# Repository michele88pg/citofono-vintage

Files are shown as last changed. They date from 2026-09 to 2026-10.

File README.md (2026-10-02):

# Pronto — a smart door intercom inside a vintage rotary phone

🇬🇧 English · [🇮🇹 Italiano](#-versione-italiana)

**Pronto** is an open-hardware circuit board that turns a vintage rotary phone into a **smart door intercom**. The phone looks and works exactly as before:

- lift the handset to talk to whoever rang;
- dial a number and the street door opens.

On top of that you get:

- a notification on your phone when someone rings;
- remote door opening;
- Home Assistant integration and, through Home Assistant, Google Home, Apple Home and Alexa.

The board has **exactly the shape of the original one** and screws into its place, with no drilling or changes to the shell.

> **Compatibility:** **Siemens / Italtel S62** phones (wall-mounted version) and **URMET 4+N** analog intercom systems, very common in Italian apartment buildings.
> Other phones and systems: see [Compatibility](docs/compatibilita.md) (in Italian).

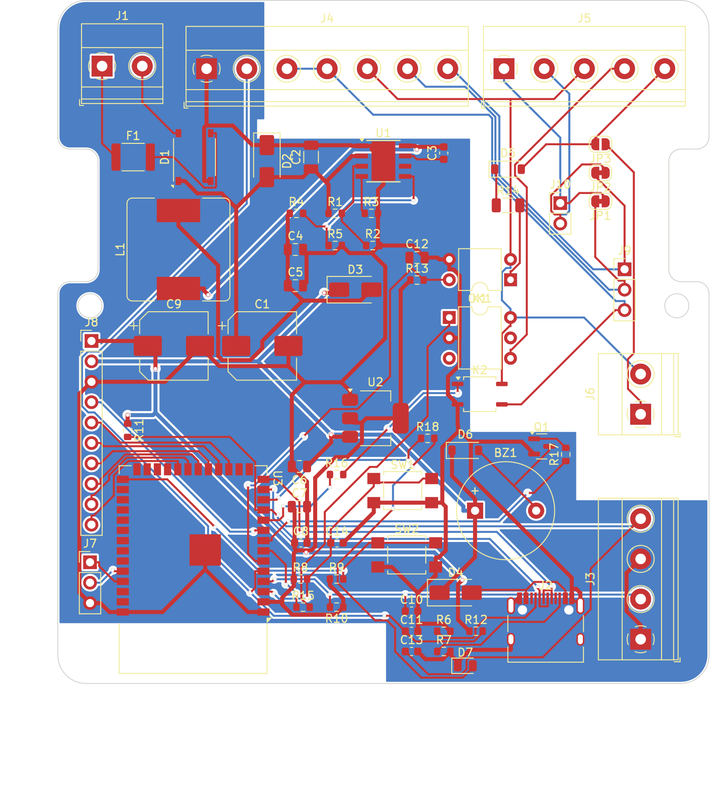
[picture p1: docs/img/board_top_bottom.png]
Pronto board rev 0.5: component side and solder side


---

> [!WARNING]
> **Prototype stage.** Board rev 0.5 has been ordered (5 assembled boards) but **has not been tested yet**.
> The firmware is validated, but not yet tried on real hardware.
> You are welcome to build one now, but expect to fix something along the way. Current status is in the [CHANGELOG](CHANGELOG.md).

## Contents

- [What it does](#what-it-does)
- [How it works, in short](#how-it-works-in-short)
- [Board pinout](#board-pinout)
- [What you need](#what-you-need)
- [Getting started](#getting-started)
- [Repository layout](#repository-layout)
- [Roadmap](#roadmap)
- [Safety](#safety)
- [Contributing](#contributing)
- [Licenses](#licenses)
- [🇮🇹 Versione italiana](#-versione-italiana)

## What it does

| Feature | How it works |
|---|---|
| **Answering** | As always: lift the handset and talk. Audio passes through in analog form; the board does not touch it |
| **Open with the dial** | Dial any number and the door opens, as many vintage intercom phones did. Optional: a **secret code** to dial |
| **Ringing** | When someone rings at the street door, the board's buzzer plays a classic double ring. The phone's original bells can be connected experimentally |
| **Phone notification** | A notification arrives with an **"Open the door"** button in it |
| **Remote opening** | From Home Assistant, the notification, a voice assistant or the board's own web page |
| **Do not disturb** | Silences the ring; the notification still arrives |
| **Auto-open** | Opens by itself when someone rings, handy for parties or expected deliveries. Turns itself off on reboot |
| **History** | Last call, last opening, call counter |
| **Local web page** | `http://citofono-vintage.local` works even without Home Assistant |
| **Remote listening and talking** | *In development:* an add-on audio board with an ES8311 codec. See [hardware/audio-board](hardware/audio-board/README.md) |

## How it works, in short

```mermaid
flowchart LR
    subgraph IMP["URMET 4+N intercom system"]
        CA["CA: call"]
        APR["9 and 6: door release"]
        FON["1 and 2: audio"]
    end
    subgraph SCH["Pronto board, inside the phone"]
        OK1["OK1 optocoupler<br/>detects the call"]
        K1["K1 PhotoMOS<br/>opens the door"]
        K2["K2 PhotoMOS<br/>simulates handset lifted"]
        ESP["ESP32-S3<br/>ESPHome firmware"]
        BZ["Buzzer"]
    end
    subgraph TEL["Rotary phone"]
        DISCO["Rotary dial"]
        CORN["Handset and hook switch"]
    end
    HA["Home Assistant<br/>notifications, Google, Apple, Alexa"]
    CA --> OK1 --> ESP
    ESP --> K1 --> APR
    ESP --> K2 -->|enables| FON
    DISCO --> ESP
    CORN --> ESP
    FON <-->|analog audio| CORN
    ESP --> BZ
    ESP <-->|WiFi| HA
```

**Isolation from the building system.** The board has no direct electrical connection to the shared intercom line. It detects the call with an optocoupler and opens the door with PhotoMOS solid-state relays, which are optically isolated. The electronics' ground stays separate from the intercom line.

The full description is in **[docs/come-funziona.md](docs/come-funziona.md)** (in Italian): every circuit block, the opening sequences, dial timing and firmware safety features.

## Board pinout

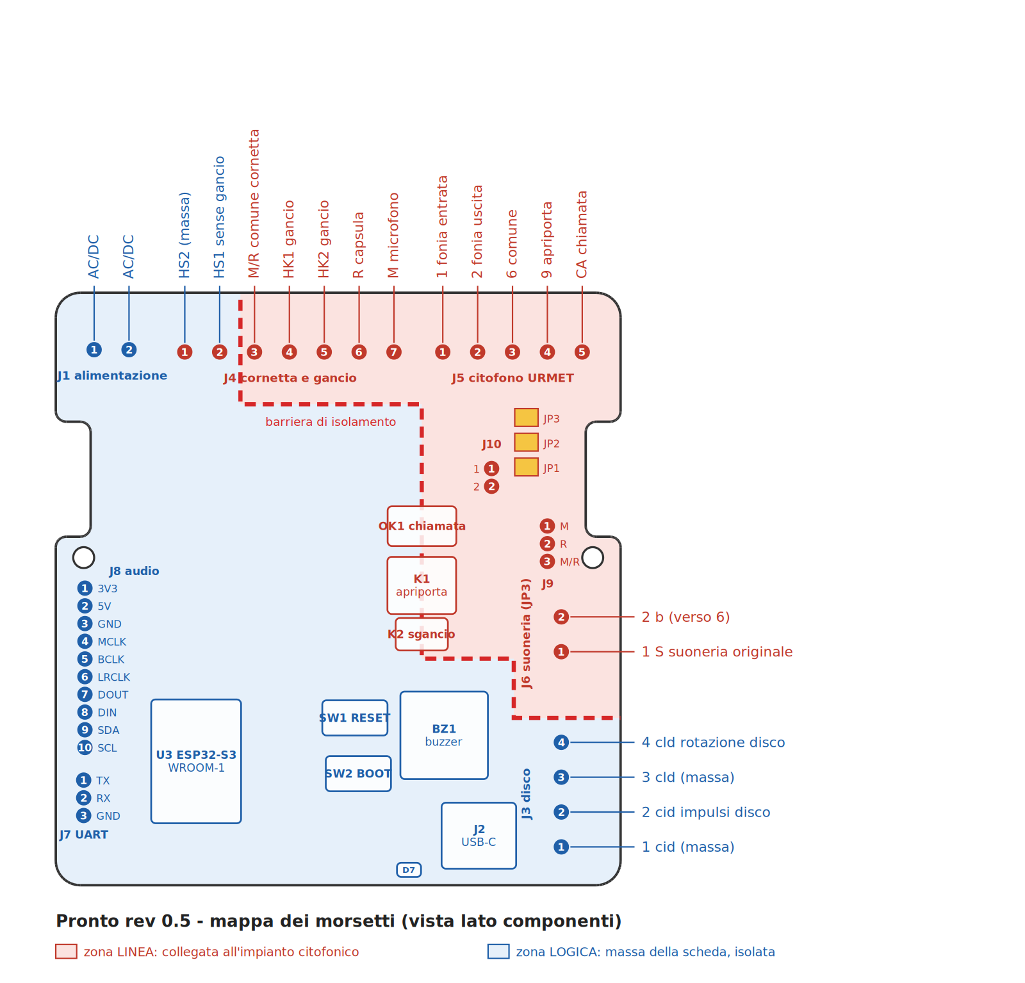
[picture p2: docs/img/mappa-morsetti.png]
Pronto rev 0.5 terminal map


The labels are in Italian. Key terms:

| Label | Meaning |
|---|---|
| alimentazione | power input |
| cornetta, capsula, microfono | handset, earpiece, microphone |
| gancio | hook switch |
| fonia entrata / uscita | audio in (from street) / audio out (to street) |
| comune | common |
| apriporta | door release |
| chiamata | call |
| suoneria | ringer bells |
| disco, impulsi, rotazione | dial, pulses, dial-in-motion contact |
| massa | ground |
| zona linea / zona logica | intercom-line side / isolated logic side |
| barriera di isolamento | isolation barrier |

Step-by-step wiring of dial, hook, handset and intercom is in [docs/installazione.md](docs/installazione.md).

## What you need

| Item | Notes |
|---|---|
| An **S62 wall phone** | Found at flea markets and online. Dial, handset and hook switch must work |
| The **Pronto** board | Order it pre-assembled from JLCPCB with the ready-made files in [`hardware/mainboard/production`](hardware/mainboard/production): see [Ordering the board](docs/ordinare-la-scheda.md) |
| Hand-soldered parts | The K1 relay (through-hole, from DigiKey/Mouser) and the screw terminals. Easy soldering |
| **Power** | URMET 4+N systems do not power the indoor unit. You need a supply on J1, **9–36 V DC or 9–24 V AC** (for example 12 V DC, 1 A), or **5 V from USB-C** |
| Home WiFi | Home Assistant is recommended but not required |
| Tools | Soldering iron, multimeter, screwdriver. A computer with [ESPHome](https://esphome.io) for the first firmware upload over USB-C |

Indicative parts cost is about €40 per board for 5 assembled prototypes. It drops a lot with larger quantities.

## Getting started

The detailed guides are currently in Italian; translations are welcome.

1. **Check compatibility** of your intercom and phone: [docs/compatibilita.md](docs/compatibilita.md)
2. **Order and assemble the board:** [docs/ordinare-la-scheda.md](docs/ordinare-la-scheda.md)
3. **Upload the firmware:** [firmware/README.md](firmware/README.md)
4. **Install the board in the phone and wire it to the intercom:** [docs/installazione.md](docs/installazione.md)
5. **Test it, one step at a time:** [docs/collaudo.md](docs/collaudo.md)
6. **Connect Home Assistant and notifications:** [docs/home-assistant.md](docs/home-assistant.md)

FAQ: [docs/faq.md](docs/faq.md)

## Repository layout

```
citofono-vintage/
├── hardware/
│   ├── mainboard/          Main board (KiCad): schematic, PCB, PDF
│   │   └── production/     Gerber, BOM and placement files ready for JLCPCB
│   ├── audio-board/        ES8311 audio board (remote listen/talk), schematic only
│   └── mechanical/         S62 board outline as DXF
├── firmware/               ESPHome firmware (+ package for the audio board)
├── home-assistant/         Example automations (notification with "Open" button)
├── docs/                   Documentation: how it works, installation, testing...
├── LICENSES/               License texts
└── CHANGELOG.md            Revision history
```

## Roadmap

- [x] Mechanical survey of the original S62 board and DXF outline
- [x] Schematic and PCB rev 0.5 in the original board's shape
- [x] ESPHome firmware with dial opening, notifications and remote opening
- [x] Audio board schematic (ES8311) for remote listening and talking
- [ ] Testing the rev 0.5 prototypes on a real URMET system
- [ ] Audio board PCB and voice calls on the phone
- [ ] Photo assembly guide and project website
- [ ] Cheaper, simplified board (ESP32 chip directly on the board, fewer parts)
- [ ] Support for other 4+N systems and other rotary phones
- [ ] English translation of the documentation

## Safety

- The board works only with **extra-low voltages**: 12 V AC call signal, at most about 30 V DC on the intercom line, 9–36 V supply. **Never connect it to 230 V mains.**
- The intercom system is often **shared by the whole building**. Make sure you are allowed to work on your indoor unit. Disconnect the old intercom only after identifying the terminals with a multimeter.
- Remote opening really opens your front door. Protect Home Assistant and the board's web page with strong passwords, and never expose the board directly to the Internet.
- The project is provided **as is**, without warranty (see [Licenses](#licenses)). Whoever builds and installs it is responsible for it.

## Contributing

The most valuable contribution right now is knowing **which intercom systems and phones it works with**.
If you try it, open a [compatibility report](../../issues/new?template=compatibilita.md), even if it does not work. Include make and model of the intercom and phone, and your measurements.

Fixes, assembly photos and translations are welcome: see [CONTRIBUTING.md](CONTRIBUTING.md).

## Licenses

| Part | License |
|---|---|
| Hardware (`hardware/`) | [CERN-OHL-S v2](LICENSES/CERN-OHL-S-2.0.txt) |
| Firmware and configuration (`firmware/`, `home-assistant/`) | [MIT](LICENSES/MIT.txt) |
| Documentation and images (`docs/`, `.md` files) | [CC BY-SA 4.0](LICENSES/CC-BY-SA-4.0.txt) |

Details are in [LICENSE.md](LICENSE.md).

**Trademarks.** Siemens, Italtel and URMET are trademarks of their respective owners. They are mentioned only to indicate compatibility. This is an independent project, not affiliated with or endorsed by them.
The S62 phone is a classic of Italian industrial design, designed by Lino Saltini in the 1960s. This project does not reproduce its shell: it only replaces the electronics inside.

---

## 🇮🇹 Versione italiana

[🇬🇧 English](#contents) · 🇮🇹 Italiano

**Pronto — il citofono smart dentro un telefono a disco**

**Pronto** è una scheda elettronica open hardware che trasforma un telefono a disco d'epoca in un **citofono smart**. Il telefono resta com'è, fuori e nell'uso:

- alzi la cornetta per parlare con chi ha suonato;
- componi un numero con il disco e il portone si apre.

In più arrivano:

- la notifica sul cellulare quando qualcuno suona;
- l'apertura del portone da remoto;
- l'integrazione con Home Assistant e, tramite Home Assistant, con Google Home, Apple Home e Alexa.

La scheda ha **esattamente la forma della scheda originale** e si avvita al suo posto, senza forare né modificare il guscio.

> **Compatibilità:** telefoni **Siemens / Italtel S62** (versione da parete) e impianti citofonici **URMET 4+N** analogici.
> Altri telefoni e impianti: vedi [Compatibilità](docs/compatibilita.md).

Scheda Pronto rev 0.5: lato componenti e lato saldature

> [!WARNING]
> **Progetto in fase di prototipo.** La scheda rev 0.5 è stata ordinata (5 esemplari assemblati) ma **non è ancora stata collaudata**.
> Il firmware è validato, ma non ancora provato sull'hardware vero.
> Se vuoi costruirla adesso sei il benvenuto, ma aspettati di dover correggere qualcosa. Lo stato aggiornato è nel [CHANGELOG](CHANGELOG.md).

### Indice

- [Cosa fa](#cosa-fa)
- [Come funziona in breve](#come-funziona-in-breve)
- [Mappa dei morsetti](#mappa-dei-morsetti)
- [Cosa serve](#cosa-serve)
- [Da dove iniziare](#da-dove-iniziare)
- [Struttura della repository](#struttura-della-repository)
- [Prossimi passi](#prossimi-passi)
- [Sicurezza](#sicurezza)
- [Contribuire](#contribuire)
- [Licenze](#licenze)

### Cosa fa

| Funzione | Come si usa |
|---|---|
| **Rispondere** | Come sempre: alzi la cornetta e parli. L'audio passa in analogico, la scheda non lo tocca |
| **Aprire con il disco** | Componi un numero qualsiasi e il portone si apre, come facevano molti citofoni-telefono d'epoca. Opzionale: un **codice segreto** da comporre |
| **Suoneria** | Quando suonano al portone, il buzzer della scheda squilla con un doppio squillo da telefono. La suoneria originale a campanelli si può collegare in via sperimentale |
| **Notifica sul cellulare** | Arriva una notifica con il pulsante **"Apri il portone"** dentro |
| **Apertura remota** | Da Home Assistant, dalla notifica, dall'assistente vocale o dalla pagina web della scheda |
| **Non disturbare** | Silenzia lo squillo; la notifica arriva comunque |
| **Apertura automatica** | Apre da sola alla chiamata, utile per feste o consegne attese. Si disattiva da sola al riavvio |
| **Storico** | Ultima chiamata, ultima apertura, contatore delle chiamate |
| **Pagina web locale** | `http://citofono-vintage.local` funziona anche senza Home Assistant |
| **Ascolto e risposta da remoto** | *In sviluppo:* scheda audio aggiuntiva con codec ES8311. Vedi [hardware/audio-board](hardware/audio-board/README.md) |

### Come funziona in breve

```mermaid
flowchart LR
    subgraph IMP["Impianto citofonico URMET 4+N"]
        CA["CA: chiamata"]
        APR["9 e 6: apriporta"]
        FON["1 e 2: fonia"]
    end
    subgraph SCH["Scheda Pronto, dentro il telefono"]
        OK1["OK1 optoisolatore<br/>sente la chiamata"]
        K1["K1 PhotoMOS<br/>apre il portone"]
        K2["K2 PhotoMOS<br/>simula la cornetta alzata"]
        ESP["ESP32-S3<br/>firmware ESPHome"]
        BZ["Buzzer"]
    end
    subgraph TEL["Telefono a disco"]
        DISCO["Disco combinatore"]
        CORN["Cornetta e gancio"]
    end
    HA["Home Assistant<br/>notifiche, Google, Apple, Alexa"]
    CA --> OK1 --> ESP
    ESP --> K1 --> APR
    ESP --> K2 -->|abilita| FON
    DISCO --> ESP
    CORN --> ESP
    FON <-->|audio analogico| CORN
    ESP --> BZ
    ESP <-->|WiFi| HA
```

**Isolamento dall'impianto.** La scheda non ha nessun collegamento elettrico diretto con l'impianto condominiale. Sente la chiamata con un optoisolatore e apre il portone con relè allo stato solido PhotoMOS, che isolano otticamente. La massa dell'elettronica resta così separata dalla linea del citofono.

Il funzionamento completo è in **[docs/come-funziona.md](docs/come-funziona.md)**: ogni blocco del circuito, le sequenze di apertura, i tempi del disco e le sicurezze del firmware.

### Mappa dei morsetti

Mappa dei morsetti della scheda Pronto rev 0.5

Il collegamento passo passo di disco, gancio, cornetta e citofono è in [docs/installazione.md](docs/installazione.md).

### Cosa serve

| Cosa | Note |
|---|---|
| Un telefono **S62 da parete** | Si trova nei mercatini e online. Deve avere disco, cornetta e gancio funzionanti |
| La scheda **Pronto** | Si ordina già assemblata da JLCPCB con i file pronti in [`hardware/mainboard/production`](hardware/mainboard/production): vedi [Ordinare la scheda](docs/ordinare-la-scheda.md) |
| Componenti da saldare a mano | Il relè K1 (a foro passante, da DigiKey/Mouser) e le morsettiere a vite. Sono saldature facili |
| **Alimentazione** | L'impianto URMET 4+N non alimenta il posto interno. Serve un alimentatore su J1, **9–36 V DC o 9–24 V AC** (per esempio 12 V DC da 1 A), oppure **5 V da USB-C** |
| WiFi di casa | Home Assistant è consigliato ma non obbligatorio |
| Attrezzatura | Saldatore, tester, cacciavite. Un computer con [ESPHome](https://esphome.io) per il primo caricamento del firmware via USB-C |

Il costo indicativo dei componenti è di circa 40 € a scheda su 5 prototipi assemblati. Scende molto con quantità maggiori.

### Da dove iniziare

1. **Verifica la compatibilità** del tuo impianto e del tuo telefono: [docs/compatibilita.md](docs/compatibilita.md)
2. **Ordina e monta la scheda:** [docs/ordinare-la-scheda.md](docs/ordinare-la-scheda.md)
3. **Carica il firmware:** [firmware/README.md](firmware/README.md)
4. **Installa la scheda nel telefono e collegala al citofono:** [docs/installazione.md](docs/installazione.md)
5. **Collauda, un passo alla volta:** [docs/collaudo.md](docs/collaudo.md)
6. **Collega Home Assistant e le notifiche:** [docs/home-assistant.md](docs/home-assistant.md)

Domande frequenti: [docs/faq.md](docs/faq.md)

### Struttura della repository

```
citofono-vintage/
├── hardware/
│   ├── mainboard/          Scheda principale (KiCad): schema, PCB, PDF
│   │   └── production/     Gerber, BOM e posizionamento pronti per JLCPCB
│   ├── audio-board/        Scheda audio ES8311 (ascolto e risposta da remoto), solo schema
│   └── mechanical/         Contorno della scheda S62 in DXF
├── firmware/               Firmware ESPHome (+ pacchetto per la scheda audio)
├── home-assistant/         Automazioni di esempio (notifica con pulsante "Apri")
├── docs/                   Documentazione: funzionamento, installazione, collaudo...
├── LICENSES/               Testi delle licenze
└── CHANGELOG.md            Storia delle revisioni
```

### Prossimi passi

- [x] Rilievo meccanico della scheda originale S62 e contorno in DXF
- [x] Schema elettrico e PCB rev 0.5 nella forma della scheda originale
- [x] Firmware ESPHome con apertura da disco, notifiche e apertura remota
- [x] Schema della scheda audio (ES8311) per ascolto e risposta da remoto
- [ ] Collaudo dei prototipi rev 0.5 su impianto URMET reale
- [ ] PCB della scheda audio e integrazione della chiamata vocale sul cellulare
- [ ] Guida fotografica al montaggio e sito del progetto
- [ ] Versione più economica e semplificata della scheda (ESP32 direttamente sulla scheda, meno componenti)
- [ ] Compatibilità con altri impianti 4+N e con altri telefoni a disco
- [ ] Traduzione in inglese della documentazione

### Sicurezza

- La scheda lavora solo con **bassissime tensioni**: 12 V AC di chiamata, al massimo circa 30 V DC sulla linea citofonica, 9–36 V di alimentazione. **Non va mai collegata alla rete a 230 V.**
- L'impianto citofonico è spesso **condominiale**. Prima di intervenire sul tuo posto interno, verifica di poterlo fare. Scollega il vecchio citofono solo dopo aver identificato i morsetti con il tester.
- L'apertura remota apre davvero il portone di casa. Proteggi Home Assistant e la pagina web della scheda con password robuste, e non esporre la scheda direttamente su Internet.
- Il progetto è fornito **così com'è**, senza garanzie (vedi [Licenze](#licenze)). Chi lo costruisce e lo installa ne è responsabile.

### Contribuire

Il contributo più prezioso adesso è sapere **su quali impianti e telefoni funziona**.
Se lo provi, apri una [segnalazione di compatibilità](../../issues/new?template=compatibilita.md), anche se non funziona. Servono marca e modello dell'impianto e del telefono, e le misure fatte.

Correzioni, foto del montaggio e traduzioni sono benvenute: vedi [CONTRIBUTING.md](CONTRIBUTING.md).

### Licenze

| Parte | Licenza |
|---|---|
| Hardware (`hardware/`) | [CERN-OHL-S v2](LICENSES/CERN-OHL-S-2.0.txt) |
| Firmware e configurazioni (`firmware/`, `home-assistant/`) | [MIT](LICENSES/MIT.txt) |
| Documentazione e immagini (`docs/`, file `.md`) | [CC BY-SA 4.0](LICENSES/CC-BY-SA-4.0.txt) |

I dettagli sono in [LICENSE.md](LICENSE.md).

**Marchi.** Siemens, Italtel e URMET sono marchi dei rispettivi proprietari. Sono citati solo per indicare la compatibilità. Questo è un progetto indipendente, non affiliato né approvato da loro.
Il telefono S62 è un classico del design industriale italiano, disegnato da Lino Saltini negli anni '60. Questo progetto non ne riproduce il guscio: ne sostituisce solo l'elettronica interna.

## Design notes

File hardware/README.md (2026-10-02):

# Hardware

| Cartella | Contenuto | Stato |
|---|---|---|
| [`mainboard/`](mainboard) | Scheda principale: sorgenti KiCad e file di produzione per JLCPCB | rev 0.5, prototipi ordinati, collaudo in corso |
| [`audio-board/`](audio-board) | Scheda audio ES8311 per ascolto e risposta da remoto | rev 0.1, solo schema |
| [`mechanical/`](mechanical) | Contorno della scheda originale S62 in DXF | rilevato su un esemplare reale |

## Licenza

Tutto il contenuto di questa cartella è rilasciato con la licenza **CERN Open Hardware Licence Version 2 – Strongly Reciprocal** (CERN-OHL-S-2.0). Il testo completo è in [`LICENSES/CERN-OHL-S-2.0.txt`](../LICENSES/CERN-OHL-S-2.0.txt).

Source location: https://github.com/michele88pg/citofono-vintage

Chi produce o distribuisce schede basate su questo progetto, anche modificate, deve:
- rendere disponibili i sorgenti con la stessa licenza;
- mantenere questa indicazione della sorgente.

Copyright © 2026 Michele Matteucci

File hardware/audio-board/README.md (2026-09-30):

# Scheda audio ES8311 (rev 0.1)

> **Stato:** solo schema. Il PCB non è ancora disegnato e la scheda non è ancora stata provata.

La scheda principale rev 0.5 apre il portone e rileva le chiamate, ma l'audio del citofono non passa dall'ESP32. Questa schedina si collega ai connettori già previsti **J8/J9/J10** e aggiunge due funzioni:

- **Ascolto e registrazione.** La voce che arriva dal posto esterno (linea 1) entra nel codec e l'ESP32 la riceve come un microfono.
- **Risposta da remoto.** La voce dal telefono esce dal codec e viene mandata sulla linea 2 al posto esterno. La cornetta resta esclusa.

Lo schema è **completo e verificato rete per rete** (netlist esportata e controllata). Il PCB conviene disegnarlo dopo il collaudo della scheda principale: vedi "Prima di ordinare".

## File

| File | Contenuto |
|---|---|
| `CitofonoAudio.kicad_sch` | Schema (formato KiCad 7, si apre in KiCad 10 che lo aggiorna) |
| `CitofonoAudio.kicad_sym` + `sym-lib-table` | Libreria di progetto: simboli ES8311 e SM-LP-5001 |
| `CitofonoAudio_schematic.pdf` | Schema stampabile |
| `BOM_AudioBoard.csv` | Distinta con i codici LCSC dei componenti principali; i campi vuoti vanno completati prima dell'ordine |

## Come funziona

```
LINEA URMET                          |  LATO LOGICA (GND scheda)
                                     |
linea 1 --C11--R4--[T1 600:600]------|--C12/C13--> MIC1P/N  ES8311 --I2S--> ESP32
          (presa ad alta impedenza)  |
linea 2 --K1 NC--> microfono cornetta|
        --K1 NA--C16--R8--[T2]-------|--R6/R7--C14/C15-- OUTP/N ES8311 <--I2S-- ESP32
linea 1 --K1 NC--> capsula cornetta  |
                                     |  TCA9554 (I2C 0x20) P0 -> Q1 -> bobina K1
```

- **Relè K1 a riposo, quindi scheda spenta o firmware in avvio:** linea e cornetta sono collegate come prima, il citofono funziona in analogico. È una scelta fail-safe.
- **Relè K1 eccitato ("Rispondi da remoto"):** la linea 2 riceve la voce dal codec e la cornetta viene esclusa. L'ascolto (T1) è sempre collegato, quindi si può registrare anche quando qualcuno usa la cornetta.
- **Isolamento:** trasformatori 600:600 da 2000 Vrms e contatti del relè. La massa della schedina è la stessa della logica della scheda principale, già isolata dalla linea.
- **Perché il TCA9554:** J8 non ha GPIO liberi. Il relè si comanda sullo stesso bus I2C del codec.

## Collegamento alla scheda principale

1. **Taglia JP1 e JP2** sulla scheda principale (il ponticello di stagno tra i due pad, con un cutter). Da quel momento è K1 della schedina a collegare linea e cornetta.
   Se togli la schedina devi richiudere JP1/JP2 con una goccia di stagno, altrimenti la cornetta resta muta.
2. Collega con cavetti Dupont femmina-femmina, **il più corti possibile (max 15 cm)**, perché MCLK è un clock a 4 MHz:
   - J1 → J8, pin 1 su pin 1 (stesso ordine)
   - J2 → J9
   - J3 → J10

## Prima di ordinare (in quest'ordine)

1. **Collaudo della scheda principale**, in particolare la prova 9 del [collaudo](../../docs/collaudo.md) (audio passante). Durante una chiamata misura con il multimetro in AC e in DC:
   - tra **1 e 6**, per sapere quanto segnale arriva (serve a confermare R4);
   - tra **2 e 6**, per sapere se c'è una tensione continua sul microfono. Se c'è, probabilmente serve montare **R9**, vedi nota nello schema.
2. **Simbolo e footprint del trasformatore.** KiCad non ha il footprint del Bourns SM-LP-5001. Sul tuo computer:
   ```
   pip install easyeda2kicad
   easyeda2kicad --full --lcsc_id=C7503474
   ```
   Poi assegna il footprint a T1 e T2. Il mio simbolo assume il **primario sui pin 1-3 e il secondario sui pin 4-6, con 2 e 5 non collegati**. Non ho potuto leggere il datasheet Bourns da qui (sito bloccato), quindi confrontalo con lo schema del datasheet o con il simbolo scaricato da easyeda2kicad. Se i numeri sono diversi, cambia solo i numeri dei pin nel simbolo: le reti restano le stesse.
3. **PCB.** Non ha vincoli di forma: va dentro il guscio del S62, dove c'è spazio. Uno spunto è 50×40 mm a 2 strati, con queste regole:
   - Condensatori di disaccoppiamento del codec attaccati ai pin. Il pad centrale (21) va a GND con 4-5 vias.
   - **Barriera di isolamento** come sulla scheda principale, larga almeno 2 mm, tra il lato linea e il lato logica:
     - lato linea: J2, J3, C11, R4, C16, R8, R9, i contatti di K1, i primari di T1 e i secondari di T2;
     - lato logica: tutto il resto;
     - T1, T2 e K1 stanno a cavallo della barriera.
   - Piano GND solo sul lato logica.
   - J1 vicino al bordo, per cavetti corti.

## Firmware

Nella cartella [`firmware`](../../firmware) c'è [`audio-es8311.yaml`](../../firmware/audio-es8311.yaml), un pacchetto ESPHome **validato con ESPHome 2026.6**. Si attiva aggiungendo tre righe a `citofono-vintage.yaml`:

```yaml
packages:
  audio: !include audio-es8311.yaml
```

Aggiunge queste entità:
- **"Rispondi da remoto (audio)"**: attiva K2 (sgancio simulato) e K1 audio, e si spegne da sola dopo 2 minuti;
- **"Volume voce verso la strada"**;
- il microfono `citofono_mic` e l'altoparlante `citofono_spk`.

**Cosa manca:** il "ponte" verso il telefono, cioè il pezzo che porta `citofono_mic`/`citofono_spk` in una chiamata sul cellulare. Il candidato è il componente della community *esphome-intercom* (SIP/RTP, integrato con Home Assistant). Lo configuriamo quando la schedina esiste, perché va provato sull'hardware vero.

## Punti da verificare al collaudo

- **Livello di ascolto:** `mic_gain` in `audio-es8311.yaml` (parte da 24 dB).
- **Livello di parlato:** prima il volume da Home Assistant. Se non basta, cambia R6/R7 (470 Ω) o R8 (1 kΩ).
- **Presenza di tensione continua su linea 2**, che decide se montare R9.
- **Pinout del trasformatore** (vedi sopra).

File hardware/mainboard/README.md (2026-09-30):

# Scheda principale (rev 0.5)

Scheda rev 0.5

## File

| File | Contenuto |
|---|---|
| `CitofonoVintage.kicad_pro` | Progetto KiCad: apri questo. Contiene regole e classi di rete |
| `CitofonoVintage.kicad_sch` | Schema elettrico, con il campo **LCSC Part#** su ogni componente |
| `CitofonoVintage.kicad_pcb` | Circuito stampato sbrogliato |
| `CitofonoVintage_schematic.pdf` | Schema stampabile |
| `board_layers.pdf` | Strati del PCB. Stampato in scala 1:1 serve a verificare l'ingombro nel telefono |
| [`production/`](production) | Gerber, BOM e CPL per l'ordine assemblato su JLCPCB |

Il progetto è stato sviluppato con **KiCad 10**, che apre anche i file dei formati precedenti. Tutti i simboli e i footprint vengono dalle librerie ufficiali di KiCad e sono incorporati nei file, quindi non servono librerie esterne.

## Caratteristiche

| | |
|---|---|
| Dimensioni | 81 × 85 mm, contorno identico alla scheda originale S62 ([DXF](../mechanical/S62_board_outline.dxf)) |
| Strati | 2, FR-4 da 1,6 mm, rame da 1 oz |
| Alimentazione | 9–36 V DC o 9–24 V AC su J1, oppure 5 V da USB-C |
| Microcontrollore | ESP32-S3-WROOM-1-N16R2 (16 MB flash, 2 MB PSRAM) |
| Interfaccia linea | Optoisolatore PC817 (chiamata), PhotoMOS TLP3546A/AQV252G (apriporta), PhotoMOS CPC1017N (sgancio) |
| Isolamento | Barriera di 2,4 mm senza rame fra zona linea e zona logica |

## Regole di progetto

| Classe | Pista | Isolamento | Via | Reti |
|---|---|---|---|---|
| Default | 0,25 mm | 0,15 mm | 0,6 / 0,3 mm | segnali |
| Power | 0,5 mm | 0,15 mm | 0,8 / 0,4 mm | +5V, +3V3, +5V_BUCK, VIN_RAW, GND, U1_SW |

Minimi: pista 0,2 mm, via 0,5/0,2 mm, distanza dal bordo 0,2 mm. Sono tutti entro le capacità standard di JLCPCB.

**Zone:**
- `GND_plane`: sullo strato inferiore, solo nella zona logica. La massa è anche sbrogliata con piste, quindi il piano non è l'unico collegamento.
- `isolamento_1…6`: le strisce della barriera. Sono vietati piste, via e rame; pad e componenti sono ammessi, perché OK1, K1 e K2 stanno a cavallo.
- `antenna_keepout`: nessun rame sotto l'antenna del modulo ESP32.

**Stato DRC:** 0 connessioni mancanti e 0 violazioni elettriche. Restano solo avvisi di serigrafia sovrapposta, cosmetici.

## Componenti principali

| Rif | Componente | LCSC | Note |
|---|---|---|---|
| U1 | LM5164DDA (buck 1 A, fino a 100 V) | C477928 | |
| U2 | AMS1117-3.3 | C6186 | |
| U3 | ESP32-S3-WROOM-1-N16R2 | C2913205 | Richiede l'assemblaggio "Standard" |
| K1 | TLP3546A(F) o AQV252G, DIP-6 a foro passante | — | Da saldare a mano, da DigiKey o Mouser |
| K2 | CPC1017N | C81521 | |
| OK1 | PC817 | C3025068 | |
| D1 | ABS10 (ponte) | C400507 | |
| D2 | SMAJ36A (TVS) | C2760877 | |
| L1 | SRR1260-470M (47 µH) | C1329363 | |
| BZ1 | TMB12A05 (buzzer attivo 5 V) | C96093 | |
| J2 | USB-C HRO TYPE-C-31-M-12 | C165948 | |

La distinta completa è in [`production/BOM_JLCPCB.csv`](production/BOM_JLCPCB.csv). I componenti da saldare a mano sono elencati in [docs/ordinare-la-scheda.md](../../docs/ordinare-la-scheda.md#componenti-da-saldare-a-mano).

## Da sistemare nella prossima revisione

- La serigrafia di J1 dice "9-40 V": il valore corretto è **9–36 V DC / 9–24 V AC**, limitato dal TVS D2.
- Nel cartiglio dello schema: la revisione è ancora "0.3" e il titolo del blocco B dice ancora "N16R8" (il modulo montato è l'N16R2).
- Avvisi di serigrafia sovrapposta da ripulire.
- Da valutare dopo il collaudo: i valori di R14 (sensibilità della chiamata) e di R15/R16 (corrente nei LED dei PhotoMOS).

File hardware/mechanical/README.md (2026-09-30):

# Meccanica

| File | Contenuto |
|---|---|
| `S62_board_outline.dxf` | Contorno della scheda originale del Siemens S62 da parete, in millimetri: 81 × 85 mm, angoli R 3,5 mm, incavi laterali per il telaio, due fori Ø 3 mm a 4 mm dai lati e a 38 mm dall'alto. Si importa in KiCad su Edge.Cuts |
| `S62_old_terminals_reference.dxf` | Riferimento con la posizione delle morsettiere originali, disegnate come croci. Serve solo per piazzare J3/J4 dove stavano i vecchi morsetti; non va importato su Edge.Cuts |

Le misure sono state rilevate con il calibro su un esemplare reale. Il raggio degli angoli non era misurabile con precisione sulla scheda originale ed è una stima.

Se hai un **S62 da tavolo** o una variante diversa, confronta la sua scheda con questo DXF e [segnala](../../../../issues/new?template=compatibilita.md) le differenze.

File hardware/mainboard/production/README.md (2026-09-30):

# File di produzione (JLCPCB)

| File | Contenuto |
|---|---|
| `CitofonoVintage_GERBER_JLCPCB.zip` | Gerber e forature, da caricare in "Add gerber file" |
| `BOM_JLCPCB.csv` | Distinta con i codici LCSC Part# |
| `CPL_JLCPCB.csv` | Posizionamento: Designator, Mid X, Mid Y, Rotation, Layer. Le coordinate sono del **centro del corpo** di ogni componente |

La procedura passo passo è in [docs/ordinare-la-scheda.md](../../../docs/ordinare-la-scheda.md).

**Note dal primo ordine:**
- Se il caricamento dei CSV dà "File processing failed", salva i file in formato **XLSX** e ricaricali.
- Il modulo ESP32-S3 richiede l'assemblaggio **Standard**, non Economic.
- K1 e le morsettiere non sono nella BOM di assemblaggio: vanno saldati a mano.

Questi file corrispondono alla revisione **0.5**. Se modifichi il progetto, rigenerali da KiCad con il plugin **Fabrication Toolkit**.

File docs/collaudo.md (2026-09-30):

# Collaudo

Le prove vanno fatte **in quest'ordine**. Ogni passo usa solo cose già verificate nei passi precedenti, così un problema salta fuori subito e si capisce da dove viene.

**Cosa serve:**
- un tester;
- il firmware già caricato (vedi [firmware/README.md](../firmware/README.md));
- il log aperto sul computer: `esphome logs citofono-vintage.yaml`.

## Prove da banco (scheda fuori dal telefono, non collegata al citofono)

| # | Prova | Risultato atteso | Se non va |
|---|---|---|---|
| 1 | Alimenta da USB-C | LED e log attivi, WiFi connesso | Misura 5 V su C6 e 3,3 V su C7 |
| 2 | Alimenta da J1 con 12 V (AC o DC) | Come sopra | Controlla il ponte D1, il fusibile F1 e il buck U1 (5 V su C4) |
| 3 | Collega il disco a J3 e componi "3" | Log: `Composta cifra 3 (3 impulsi)` | Se la cifra è sbagliata, vedi la nota sul disco più sotto |
| 4 | Componi "0" | `Composta cifra 0 (10 impulsi)` | |
| 5 | Collega il gancio a J4 1-2, alza e abbassa la cornetta | "Cornetta alzata" ON/OFF | Se lo stato è al contrario, cambia `inverted` del sensore `handset` nel firmware |
| 6 | Premi il pulsante BOOT (SW2) | "Apertura portone" nel log e **continuità fra J5-9 e J5-6** per 1,5 s | R15, K1 (verso di montaggio!) |
| 7 | Premi "Test suoneria" da Home Assistant o dalla pagina web | Il buzzer suona 3 doppi squilli | Q1, R17, BZ1 |

## Prove sull'impianto

| # | Prova | Risultato atteso | Se non va |
|---|---|---|---|
| 8 | Collega J5 al citofono e fai suonare dal portone | "Chiamata in corso" ON, squillo, evento "Campanello" in Home Assistant | Misura circa 12 V AC fra 6 e CA; controlla OK1, D5, R14 |
| 9 | Alza la cornetta durante una chiamata e parla | Audio nei due sensi, come con il citofono originale | JP1/JP2 devono essere chiusi; controlla il cablaggio di J4 3, 6, 7 e il contatto HK1-HK2 |
| 10 | Componi un numero a cornetta alzata | Il portone si apre | Aumenta "Durata apertura portone" |
| 11 | "Apri portone" da Home Assistant a cornetta abbassata | Il portone si apre | Prova ad attivare o disattivare "Apertura remota con sgancio simulato" |
| 12 | Componi un numero a cornetta **abbassata** | Il portone si apre (se non hai attivato "Rotella apre solo a cornetta alzata") | Alcuni impianti accettano l'apriporta solo con la fonia attiva: in quel caso attiva l'opzione e apri a cornetta alzata |

## Note

- **Disco.** Il firmware conta gli impulsi del contatto `cid` (J3 1-2) e chiude la cifra quando il contatto `cld` (J3 3-4) segnala il ritorno del disco, oppure dopo 300 ms senza impulsi.
  - Se le cifre risultano sbagliate di ±1, il problema è quasi sempre il filtro anti-rimbalzo (`delayed_on/off: 8ms` del sensore `dial_pulse`): prova 5 ms oppure 12 ms.
  - Se il disco è molto lento o molto veloce, fallo revisionare: deve fare circa 10 impulsi al secondo.
- **Sgancio simulato.** Se il passo 11 funziona anche con l'opzione disattivata, lasciala spenta: l'apertura remota è più rapida e la linea condominiale non viene impegnata.
- **Durata dell'apertura.** 1,5 s va bene per la maggior parte delle serrature elettriche; alcune vogliono 2–3 s.

## Misure da annotare (aiutano tutti)

Se fai il collaudo su un impianto nuovo, annota queste misure e condividile in una [segnalazione di compatibilità](../../../issues/new?template=compatibilita.md):

| Misura | Come | Tester |
|---|---|---|
| Tensione di chiamata | Fra CA e 6 mentre suonano | V AC |
| Tensione su 9 a riposo | Fra 9 e 6, cornetta abbassata | V DC e V AC |
| Tensione sulla fonia | Fra 1 e 6 e fra 2 e 6, cornetta alzata, durante una chiamata | V DC e V AC |
| Apertura a cornetta abbassata | Passo 12 | sì / no |
| Serve lo sgancio simulato | Passo 11 | sì / no |

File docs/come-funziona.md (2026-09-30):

# Come funziona

Questa pagina descrive la scheda **rev 0.5** blocco per blocco e il comportamento del firmware.

Gli schemi completi sono in [`hardware/mainboard/CitofonoVintage_schematic.pdf`](../hardware/mainboard/CitofonoVintage_schematic.pdf). I riferimenti dei componenti (R14, K1, ...) sono quelli dello schema.

- [1. Il principio: come funziona un citofono 4+N](#1-il-principio-come-funziona-un-citofono-4n)
- [2. Architettura della scheda](#2-architettura-della-scheda)
- [3. Blocco A1: alimentazione](#3-blocco-a1-alimentazione)
- [4. Blocco A2: interfaccia verso il citofono](#4-blocco-a2-interfaccia-verso-il-citofono)
- [5. Blocco A3: interfaccia verso il telefono](#5-blocco-a3-interfaccia-verso-il-telefono)
- [6. Blocco B: il cervello (ESP32-S3)](#6-blocco-b-il-cervello-esp32-s3)
- [7. Isolamento e layout](#7-isolamento-e-layout)
- [8. Il firmware](#8-il-firmware)
- [9. Scheda audio (in sviluppo)](#9-scheda-audio-in-sviluppo)

---

## 1. Il principio: come funziona un citofono 4+N

Nei citofoni analogici "4+N" ogni appartamento è collegato al posto esterno (la pulsantiera sul portone) da alcuni fili comuni a tutti più un filo di chiamata personale. Sull'impianto **URMET 4+N** (scheda di chiamata CS 1133) usato per sviluppare il progetto, i morsetti del posto interno sono:

| Morsetto | Funzione |
|---|---|
| **1** | Fonia entrata: la voce che arriva dalla strada, va alla capsula della cornetta |
| **2** | Fonia uscita: la voce dal microfono della cornetta verso la strada |
| **6** | Comune (riferimento per tutti gli altri) |
| **9** | Apriporta: **chiudendo 9 con 6 il portone si apre** |
| **CA** | Chiamata: quando qualcuno suona, fra **CA e 6** arrivano circa **12 V AC** |

In un citofono tradizionale:
- il pulsante a chiave chiude 9 con 6;
- il ronzatore è collegato fra CA e 6;
- quando alzi la cornetta, il gancio collega il comune della cornetta al morsetto 6 e "accende" la fonia.

La scheda Pronto fa esattamente queste cose, ma con componenti elettronici comandati dal disco del telefono e dall'ESP32.

> **Importante:** il posto interno di un 4+N **non riceve alimentazione** dalla linea. La tensione su CA c'è solo durante la chiamata. Per questo la scheda va alimentata a parte (vedi il blocco A1).

## 2. Architettura della scheda

La scheda è divisa in due zone separate da una **barriera di isolamento**, cioè una striscia senza rame sul circuito stampato:

```mermaid
flowchart TB
    subgraph LINEA["ZONA LINEA (collegata all'impianto)"]
        J5["J5: morsetti URMET<br/>1, 2, 6, 9, CA"]
        J4L["J4: cornetta e gancio<br/>lato fonia"]
        J6["J6: suoneria originale"]
    end
    subgraph BARRIERA["BARRIERA DI ISOLAMENTO"]
        OK1["OK1 PC817"]
        K1["K1 PhotoMOS"]
        K2["K2 PhotoMOS"]
    end
    subgraph LOGICA["ZONA LOGICA (massa della scheda)"]
        PWR["Alimentazione<br/>J1 e USB-C"]
        ESP["ESP32-S3"]
        J3["J3: disco"]
        J4S["J4: contatto gancio<br/>per il sense"]
        BZ["Buzzer, LED, pulsanti"]
    end
    J5 --- OK1 & K1 & K2
    OK1 --- ESP
    K1 --- ESP
    K2 --- ESP
    PWR --> ESP
    J3 --> ESP
    J4S --> ESP
    ESP --> BZ
```

- **Zona linea:** tutto ciò che tocca i fili dell'impianto condominiale.
- **Zona logica:** l'ESP32, l'alimentazione e i contatti "asciutti" del telefono (disco e un contatto del gancio).
- **A cavallo della barriera:** solo tre componenti a isolamento ottico. Il loro lato LED sta da una parte e il lato uscita dall'altra.

## 3. Blocco A1: alimentazione

```
J1 (AC o DC) → F1 fusibile ripristinabile 0,5 A → D1 ponte ABS10 → D2 TVS SMAJ36A
            → U1 LM5164 (buck, 5 V, 1 A) → D3 ─┐
USB-C VBUS  ─────────────────────────────→ D4 ─┴→ +5V → U2 AMS1117 → +3V3 → ESP32
```

- **Ingresso J1:** polarità indifferente, AC o DC, grazie al ponte D1.
  - **DC da 9 a 36 V.** Il TVS D2 protegge dai disturbi e inizia a condurre oltre i 36 V circa.
  - **AC da 9 a 24 V**, per esempio il secondario 12 V AC di un trasformatore citofonico.
- **U1 LM5164** (Texas Instruments): convertitore buck da 1 A con ingresso fino a 100 V e consumo a vuoto bassissimo.
  - RON = 49,9 kΩ, frequenza circa 250 kHz.
  - Partitore R4/R5 = 100 k / 31,6 k, uscita 5,0 V.
  - Partitore R1/R2: sotto circa 7,5 V il convertitore resta spento (UVLO) invece di funzionare male.
- **OR con l'USB:** D3 e D4 (Schottky SS34) permettono di alimentare la scheda da J1, da USB-C o da entrambi senza conflitti. L'USB basta anche per l'uso quotidiano, non solo per programmare.
- **U2 AMS1117-3.3:** LDO da 1 A per l'ESP32.
- **C9 da 470 µF:** vicino al modulo, assorbe i picchi di corrente del WiFi (300–500 mA) che altrimenti farebbero riavviare l'ESP32 (brown-out).

**Consumo:** qualche decina di mA a riposo, con picchi durante la trasmissione WiFi. Un alimentatore da 12 V DC 1 A o un caricatore USB da 5 V 1 A sono più che sufficienti.

## 4. Blocco A2: interfaccia verso il citofono

### Rilevamento della chiamata: OK1

```
CA ── D5 (1N4148W) ── R14 15 kΩ ── LED di OK1 ── 6          (zona linea)
                                   transistor di OK1 → IO6   (zona logica)
```

- Durante la chiamata, i 12 V AC su CA vengono raddrizzati a semionda da D5 e accendono il LED dell'optoisolatore PC817. Il transistor porta a massa l'ingresso IO6 (pull-up R13 10 kΩ).
- R14 è dimensionata sul caso peggiore di 31 V DC (circa 2 mA nel LED) e funziona ancora bene a 12 V AC.
- C12 (4,7 µF) e il filtro firmware da 1,5 s trasformano gli impulsi a 50 Hz in un segnale stabile "chiamata in corso".

### Apriporta: K1

- **K1** è un relè allo stato solido PhotoMOS (**TLP3546A** oppure **AQV252G**, entrambi DIP-6 a foro passante).
- L'ESP32 accende il suo LED da IO7 tramite R15 (390 Ω). L'uscita chiude il contatto **9 ↔ 6**, esattamente come il pulsante a chiave del citofono originale.
- Il PhotoMOS è bidirezionale (AC e DC, fino a 60 V). Funziona sia con i circuiti apriporta in alternata sia con quelli in continua.
- Non ha parti in movimento né rimbalzi e non fa rumore.

### Sgancio simulato: K2

- **K2** (CPC1017N, PhotoMOS 60 V 1 A) è collegato **in parallelo al contatto del gancio** che unisce il comune della cornetta al morsetto 6. L'ESP32 lo comanda da IO17 tramite R16 (560 Ω).
- Chiudendo K2 la scheda "alza la cornetta" elettricamente. Su molti impianti URMET serve perché l'apriporta venga accettato anche quando nessuno ha alzato la cornetta, ed è anche il modo di aprire la fonia per la futura risposta da remoto.
- Se sul tuo impianto non serve, il firmware permette di disattivarlo (vedi il paragrafo 8).

## 5. Blocco A3: interfaccia verso il telefono

### Il disco combinatore (J3)

Il disco dell'S62 ha due contatti:

| Contatto | Morsetti J3 | Comportamento | GPIO |
|---|---|---|---|
| **cid**: impulsi | 1-2 | Chiuso a riposo, **si apre a ogni impulso** | IO4 |
| **cld**: rotazione | 3-4 | Chiuso **mentre il disco torna indietro** | IO18 |

- Entrambi i contatti chiudono verso massa, con pull-up da 10 kΩ e un condensatore da 100 nF contro i disturbi.
- Il disco genera **10 impulsi al secondo**: circa 60 ms di apertura e 40 ms di chiusura.
- La cifra è il numero di impulsi, e 10 impulsi valgono **0**.

### Gancio e cornetta (J4, 7 morsetti)

| J4 | Nome | Collegamento | Zona |
|---|---|---|---|
| 1 | HS2 | Secondo contatto del gancio: massa | logica |
| 2 | HS1 | Secondo contatto del gancio: sense, IO5 | logica |
| 3 | M/R | Filo comune della cornetta | linea |
| 4 | HK1 | Contatto del gancio che accende la fonia: lato cornetta | linea |
| 5 | HK2 | Contatto del gancio che accende la fonia: lato morsetto 6 | linea |
| 6 | R | Capsula ricevente della cornetta | linea |
| 7 | M | Microfono della cornetta | linea |

- Il gancio dell'S62 ha più contatti e se ne usano **due indipendenti**:
  - **HK1-HK2** collega la cornetta al morsetto 6, come nel citofono originale;
  - **HS1-HS2** dice all'ESP32 se la cornetta è alzata.

  Sono due contatti separati, così la zona logica non tocca mai la linea.
- **Audio passante:** i ponticelli a saldare **JP1** (linea 1 ↔ capsula R) e **JP2** (linea 2 ↔ microfono M) sono **chiusi di fabbrica**. La voce passa in analogico come nel citofono originale: la scheda non la elabora e non la registra.
- JP1 e JP2 si tagliano solo se si monta la [scheda audio](#9-scheda-audio-in-sviluppo).

### Suoneria originale (J6, opzionale)

- Il suono della chiamata di serie lo fa il buzzer BZ1 della scheda.
- Chi vuole provare i campanelli originali dell'S62 (circa 1700 Ω) può collegarli a J6 e chiudere il ponticello **JP3**, che li mette fra CA e 6.
- È una **prova sperimentale**: non tutti gli impianti hanno abbastanza potenza sulla linea di chiamata per muovere i campanelli.

## 6. Blocco B: il cervello (ESP32-S3)

- **Modulo ESP32-S3-WROOM-1-N16R2:** 16 MB di flash, 2 MB di PSRAM, WiFi e Bluetooth, antenna integrata.
- **USB-C nativa** (IO19/IO20): programmazione, log e alimentazione. Non serve un convertitore USB-seriale.
  - Le resistenze CC da 5,1 kΩ fanno riconoscere la scheda a qualsiasi caricatore USB-C.
- **Pulsanti:** SW1 = RESET; SW2 = BOOT, che nel firmware serve anche a provare l'apriporta.
- **Buzzer BZ1:** TMB12A05, attivo, 5 V, pilotato da Q1 (MMBT3904) su IO15.
- **LED di stato D7:** IO8.
- **J7:** UART di debug (TX, RX, GND).
- **J8/J9/J10:** connettori di espansione per la scheda audio.
  - J8 porta 3,3 V, 5 V, GND, I2S (MCLK, BCLK, LRCLK, DOUT, DIN) e I2C (SDA, SCL).
  - J9 porta i fili della cornetta.
  - J10 porta la fonia di linea.

### Mappa dei GPIO

| Segnale | GPIO | Segnale | GPIO |
|---|---|---|---|
| DIAL_PULSE (disco, cid) | IO4 | I2S_BCLK | IO9 |
| HOOK_SENSE (gancio) | IO5 | I2S_LRCLK | IO10 |
| CALL_SENSE (OK1) | IO6 | I2S_DOUT | IO11 |
| DRIVE_OPEN (K1) | IO7 | I2S_DIN | IO12 |
| LED_STATUS | IO8 | I2C_SDA | IO13 |
| BUZZER | IO15 | I2C_SCL | IO14 |
| DRIVE_HOOK (K2) | IO17 | I2S_MCLK | IO16 |
| DIAL_ACTIVE (disco, cld) | IO18 | USB D-/D+ | IO19/IO20 |

- IO0 è il pulsante BOOT e EN è il RESET.
- Le uscite dei relè sono su pin che restano a livello basso durante l'avvio, così **nessun relè si chiude all'accensione**.

## 7. Isolamento e layout

- **PCB a 2 strati** con il contorno identico alla scheda originale dell'S62: 81 × 85 mm, due fori Ø 3 mm a 4 mm dal bordo e a 38 mm dall'alto, incavi laterali per il telaio. Il DXF è in [`hardware/mechanical`](../hardware/mechanical).
- **Barriera di isolamento:** una striscia larga 2,4 mm senza piste, via o rame su entrambi gli strati. Separa la zona linea (in alto e sul lato destro: morsetti J4, J5 e J6) dalla zona logica. OK1, K1 e K2 sono gli unici componenti a cavallo.
- **Piano di massa** solo nella zona logica, sullo strato inferiore.
- **Zona antenna:** nessun rame sotto l'antenna del modulo ESP32 (fascia in basso a sinistra), per non ridurre la portata del WiFi.
- **Classi di rete:**
  - piste di potenza da 0,5 mm (+5V, +3V3, VIN, GND);
  - segnali da 0,25 mm;
  - isolamento minimo 0,15 mm.

  Sono tutti valori standard di JLCPCB.

## 8. Il firmware

Il firmware è scritto in [ESPHome](https://esphome.io), un linguaggio di configurazione in YAML, ed è in [`firmware/citofono-vintage.yaml`](../firmware/citofono-vintage.yaml). Si modifica senza scrivere codice C++ e si aggiorna via WiFi.

### Quando suonano

```mermaid
sequenceDiagram
    participant V as Visitatore
    participant U as Posto esterno
    participant P as Scheda Pronto
    participant HA as Home Assistant
    participant T as Il tuo cellulare
    V->>U: preme il pulsante
    U->>P: 12 V AC su CA (OK1)
    P->>P: squilla il buzzer (se "Non disturbare" è spento e la cornetta è giù)
    P->>HA: evento "Campanello: chiamata"
    HA->>T: notifica con pulsante "Apri il portone"
    T->>HA: tocchi "Apri il portone"
    HA->>P: pulsante "Apri portone"
    P->>U: K2 chiude (sgancio simulato), dopo 400 ms K1 chiude 9-6 per 1,5 s
    U->>V: il portone si apre
```

- **Squillo:** doppio squillo breve ripetuto tre volte, come un vecchio telefono. Si ferma appena alzi la cornetta.
- **Evento `Campanello`:** di tipo `doorbell` in Home Assistant, con due tipi di evento, `chiamata` e `apertura`.
- **Contatore e "Ultima chiamata":** si aggiornano a ogni squillo.

### Aprire con il disco

1. Il firmware conta gli impulsi di `cid`.
2. Chiude la cifra quando `cld` segnala che il disco è tornato a riposo, oppure dopo **300 ms senza impulsi** se `cld` non è cablato.
3. Poi decide se aprire:
   - se il **Codice rotella** è vuoto, **qualsiasi cifra apre**, come i citofoni-telefono d'epoca;
   - se il codice è impostato (fino a 8 cifre), apre quando **le ultime cifre composte coincidono** con il codice. Le cifre si azzerano dopo 6 s di pausa o quando riagganci;
   - con l'opzione **"Rotella apre solo a cornetta alzata"**, il disco apre solo se la cornetta è sollevata.
4. L'apertura locale chiude solo K1: la cornetta è già alzata, quindi la linea è attiva.

### Aprire da remoto

- Il pulsante **"Apri portone"** (Home Assistant, pagina web, notifica, assistente vocale) esegue questa sequenza:
  1. chiude K2 per simulare la cornetta alzata;
  2. aspetta 400 ms;
  3. chiude K1 per la durata impostata;
  4. riapre K2.
- Con l'opzione **"Apertura remota con sgancio simulato"** spenta, si salta K2: è più rapido, se l'impianto lo permette.
- L'opzione **"Apertura automatica alla chiamata"** apre da sola 2 secondi dopo ogni chiamata. Si spegne sempre al riavvio, per non restare accesa per errore.

### Sicurezze

| Rischio | Protezione |
|---|---|
| Relè chiusi all'accensione o dopo un aggiornamento | All'avvio il firmware apre sempre K1 e K2; durante il boot i pin di comando restano bassi o scollegati, quindi i LED dei PhotoMOS sono spenti |
| Portone che resta aperto per un errore | K1 si riapre da solo dopo **5 s**, qualunque cosa succeda |
| Linea condominiale impegnata a lungo | K2 si riapre da solo dopo **2 minuti** |
| Accesso non autorizzato | API di Home Assistant cifrata; pagina web e aggiornamenti OTA protetti da password |
| WiFi di casa non raggiungibile | Il citofono continua a funzionare: squilla e apre con il disco. La scheda crea anche la rete **Citofono-Setup** per riconfigurare il WiFi dal telefono |

Il citofono **non dipende dal WiFi né da Home Assistant** per le funzioni di base. Se la scheda è spenta, la cornetta funziona ancora in analogico: l'audio passa per JP1/JP2 e il gancio chiude la fonia. Non si possono però aprire il portone né sentire la chiamata.

## 9. Scheda audio (in sviluppo)

Nella scheda principale l'audio passa in analogico e l'ESP32 non lo sente. Per **ascoltare, registrare e rispondere da remoto** c'è una scheda aggiuntiva che si collega a J8/J9/J10:

- **codec ES8311:** converte l'audio fra analogico e digitale e lo scambia con l'ESP32 via I2S;
- **due trasformatori audio 600:600**, che isolano il codec dalla linea;
- **un relè** che, quando è attivo, passa la linea dal microfono della cornetta al codec. A riposo tutto funziona come senza scheda audio.

Stato: schema pronto, PCB da disegnare dopo il collaudo della scheda principale. Dettagli in [`hardware/audio-board`](../hardware/audio-board/README.md).

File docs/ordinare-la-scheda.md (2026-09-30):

# Ordinare e montare la scheda

La scheda si ordina **già assemblata** da [JLCPCB](https://jlcpcb.com): arrivano PCB e componenti SMD saldati. A mano restano solo il relè K1 e le morsettiere, tutti a foro passante e facili da saldare.

I file pronti sono in [`hardware/mainboard/production`](../hardware/mainboard/production):

| File | Cosa contiene |
|---|---|
| `CitofonoVintage_GERBER_JLCPCB.zip` | Gerber e forature del PCB |
| `BOM_JLCPCB.csv` | Distinta componenti con i codici **LCSC Part#** |
| `CPL_JLCPCB.csv` | Posizione e rotazione dei componenti (coordinate del centro del corpo) |

## Ordine su JLCPCB, passo passo

1. **Carica il Gerber:** "Order now" e poi "Add gerber file" con lo zip. Le opzioni da scegliere:

   | Opzione | Valore |
   |---|---|
   | Base material | FR-4 |
   | Layers | 2 |
   | Dimensions | le rileva da solo, circa 81 × 85 mm |
   | PCB Qty | 5, il minimo |
   | PCB Thickness | 1,6 mm |
   | Surface finish | HASL lead-free oppure ENIG |
   | Mark on PCB | "Remove Mark", se disponibile |

   Il resto va lasciato di default.

2. **Attiva "PCB Assembly":**
   - lato **Top**;
   - **Standard** e non Economic: il modulo ESP32-S3 si può montare solo con l'assemblaggio Standard;
   - quantità: 2 oppure 5.

3. **BOM e CPL:** carica `BOM_JLCPCB.csv` e `CPL_JLCPCB.csv`.
   - Se il sito rifiuta i CSV ("File processing failed"), aprili e salvali in formato **XLSX**, poi ricaricali.
4. **Controlla la lista componenti.** Alcune voci risultano senza codice, ed è voluto: sono le parti da saldare a mano, elencate sotto. Deselezionale.
   - Se un componente è esaurito, cercane uno equivalente con **lo stesso footprint**.
5. **Controlla l'anteprima di posizionamento.** Ogni componente deve stare sulla sua impronta, con il pin 1 nel verso giusto.
   - Attenzione a U3 (ESP32), J2 (USB-C), OK1, BZ1, diodi e condensatori elettrolitici.
   - Se un pezzo è ruotato o spostato, correggilo nell'anteprima: JLCPCB fa comunque una verifica manuale (DFM) prima di produrre.
6. Conferma e paga. Il primo ordine di prototipi (5 schede assemblate) è costato circa 195 USD, spedizione compresa.

## Componenti da saldare a mano

| Rif | Cosa | Dove comprarlo | Note |
|---|---|---|---|
| **K1** | PhotoMOS DIP-6 a foro passante: **TLP3546A(F)** (Toshiba) oppure **AQV252G** (Panasonic) | DigiKey, Mouser | Su LCSC c'è solo la versione SMD, che non entra |
| **J1, J6** | Morsettiera 2 poli, passo **5,0 mm** | LCSC C474950 (KF128-5.0-2P) | |
| **J3** | Morsettiera 4 poli, passo 5,0 mm | 2× C474950 | I KF128 si incastrano di fianco mantenendo il passo |
| **J5** | Morsettiera 5 poli, passo 5,0 mm | C474950 + C474951 (KF128-5.0-3P) | |
| **J4** | Morsettiera 7 poli, passo 5,0 mm | 2× C474950 + 1× C474951 | Incastrale fra loro prima di infilarle |
| **J7, J8, J9, J10** | Pin header maschio 2,54 mm | C2337 (strip da 40 da spezzare) | Opzionali: servono per il debug e la scheda audio |

> **Attenzione al passo:** servono morsettiere a **5,0 mm**, non 5,08 mm. Su 7 poli la differenza si accumula a quasi mezzo millimetro e i pin non entrano nei fori.

**Per 5 schede:** 5× K1, 25× C474950, 10× C474951, 1× C2337.

## Montaggio

1. **K1:** rispetta il verso. Il pin 1 (tacca o puntino) va verso il segno sulla serigrafia. Salda due piedini opposti, controlla che sia appoggiato alla scheda, poi salda gli altri.
2. **Morsettiere:** montale con l'ingresso dei fili verso il bordo della scheda. Tienile premute mentre saldi il primo pin di ognuna.
3. **Header:** J8/J9/J10 solo se monterai la scheda audio; J7 solo per il debug seriale.
4. **Controllo prima di alimentare:**
   - con il tester, fra +5V e GND e fra +3V3 e GND **non deve esserci un corto**. Le piazzole sono accessibili su C6/C7;
   - JP1 e JP2 devono essere chiusi (ponticello di stagno di fabbrica);
   - JP3 deve essere aperto.

Poi passa al [firmware](../firmware/README.md).

## Modificare il progetto

Il progetto è in KiCad, nella cartella [`hardware/mainboard`](../hardware/mainboard):
- schema: `CitofonoVintage.kicad_sch`;
- circuito stampato: `CitofonoVintage.kicad_pcb`;
- regole e classi di rete: `CitofonoVintage.kicad_pro`.

I file di produzione si rigenerano con il plugin **Fabrication Toolkit** (Bennymeg) di KiCad, che produce direttamente Gerber, BOM e CPL nel formato di JLCPCB. Il codice LCSC di ogni componente è nel campo **"LCSC Part#"** dello schema.

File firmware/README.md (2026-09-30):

# Firmware (ESPHome)

Firmware per la scheda rev 0.5 (Siemens S62 su impianto URMET 4+N), scritto in ESPHome.
Configurazione **validata con ESPHome 2026.6** e codice C++ generato correttamente; la compilazione finale va fatta sul tuo computer (vedi sotto).

## Cosa fa

| Funzione | Come |
|---|---|
| **Apertura con la rotella** | Componi un numero qualsiasi → il portone si apre (come molti citofoni-telefono d'epoca). Opzionale: un **codice segreto** da comporre, impostabile da Home Assistant o dalla pagina web |
| **Apertura remota** | Pulsante "Apri portone" in Home Assistant o nella pagina web. Prima simula lo sgancio (K2) per abilitare la linea URMET, poi chiude K1 |
| **Chiamata** | Rileva quando suonano al posto esterno: squilla il buzzer, genera un evento "Campanello" in Home Assistant, aggiorna "Ultima chiamata" e il contatore |
| **Notifica sul telefono** | Con le automazioni in [`home-assistant/`](../home-assistant): notifica con il pulsante "Apri il portone" dentro |
| **Non disturbare** | Silenzia il buzzer; la notifica arriva comunque |
| **Apertura automatica** | Se attivata, apre da sola 2 s dopo la chiamata (feste, consegne attese). Si spegne da sola al riavvio |
| **Pagina web locale** | `http://citofono-vintage.local`: funziona anche senza Home Assistant |
| **Sicurezze** | Relè sempre aperti all'accensione; K1 non resta chiuso più di 5 s, K2 non più di 2 minuti |

Google Home, Apple Home e Alexa si collegano **tramite Home Assistant**: vedi [docs/home-assistant.md](../docs/home-assistant.md).

## Primo caricamento

1. Installa ESPHome sul computer: `pip install esphome` (oppure l'add-on ESPHome in Home Assistant).
2. Copia `secrets.yaml.example` come `secrets.yaml` e compila WiFi e password.
   Per la chiave API: `openssl rand -base64 32`.
3. Collega la scheda al computer con un cavo **USB-C dati** (non solo ricarica).
4. `esphome run citofono-vintage.yaml` → scegli la porta USB.
   Se la scheda non viene vista: tieni premuto **BOOT**, premi e rilascia **RESET**, poi rilascia BOOT.
5. Gli aggiornamenti successivi arrivano via WiFi: `esphome run citofono-vintage.yaml` e scegli l'indirizzo di rete.

Se il WiFi configurato non è raggiungibile, la scheda crea la rete **Citofono-Setup**: collegati dal telefono e scegli la rete di casa.

## Collaudo

Il piano di collaudo passo passo, prima da banco e poi sull'impianto, è in [docs/collaudo.md](../docs/collaudo.md).

## File

- `citofono-vintage.yaml` — il firmware
- `secrets.yaml.example` — modello delle password (il vero `secrets.yaml` non va mai pubblicato)
- [`home-assistant/automazioni-citofono.yaml`](../home-assistant/automazioni-citofono.yaml) — notifica con pulsante "Apri"
- `audio-es8311.yaml` — pacchetto opzionale per la scheda audio ES8311 (vedi [hardware/audio-board](../hardware/audio-board/README.md)); si attiva con `packages: audio: !include audio-es8311.yaml`

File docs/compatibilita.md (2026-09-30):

# Compatibilità

Questa tabella viene aggiornata con le prove della community. Se provi la scheda su un impianto o su un telefono che non è elencato, [apri una segnalazione di compatibilità](../../../issues/new?template=compatibilita.md), anche se non funziona: serve anche quella.

## Telefoni

| Telefono | Stato | Note |
|---|---|---|
| **Siemens S62 da parete** | ✅ Progettata su questo | Forma, fori e posizione dei morsetti rilevati su un esemplare reale |
| **Italtel S62 da parete** | ✅ Atteso compatibile | Stesso telefono: dagli anni '80 lo stesso modello è stato prodotto e marchiato Italtel |
| Siemens / Italtel S62 da tavolo | ❓ Da verificare | L'elettronica è la stessa, ma la scheda e il suo fissaggio potrebbero essere diversi. Se ne hai uno, misura la scheda e confrontala con il [DXF](../hardware/mechanical/S62_board_outline.dxf) |
| Altri telefoni a disco (Face, Bobo, Grillo…) | ❌ Non adatta come forma | L'elettronica sarebbe riutilizzabile, ma la scheda non entra. Serve un nuovo contorno del PCB: contributi benvenuti |

**Cosa deve funzionare nel telefono:**
- il **disco**, che deve tornare indietro regolare e senza impuntarsi;
- il **gancio** con almeno due contatti;
- la **cornetta**, con capsula e microfono.

La vecchia scheda e le vecchie morsettiere vengono tolte.

## Impianti citofonici

| Impianto | Stato | Note |
|---|---|---|
| **URMET 4+N analogico** (posto esterno con scheda CS 1133) | 🔧 In collaudo | Impianto di sviluppo. Morsetti confermati con misure sul campo: 1, 2, 6, 9, CA |
| Altri URMET 4+N analogici | ❓ Probabile | Stessa logica di morsetti; verifica con il tester (vedi sotto) |
| Altri 4+N analogici (BTicino, Comelit, Elvox, Farfisa, Terraneo…) | ❓ Possibile | Il principio è identico (chiamata in AC, apriporta a contatto, fonia su due fili), ma **la numerazione dei morsetti è diversa**. Serve identificare i fili con il tester |
| Impianti digitali o a 2 fili (URMET 2Voice, BTicino 2 fili, Comelit Simplebus…) | ❌ Non supportati | Usano un bus digitale: serve un'interfaccia diversa |
| Videocitofoni | ❌ Non supportati | |

### Come riconoscere il tuo impianto

1. **Guarda il citofono che hai in casa.** Un 4+N analogico ha di solito **da 4 a 6 fili** su una morsettiera con numeri (1, 2, 6, 9…) o sigle.
   - Se hai solo 2 fili, è quasi certamente un impianto digitale.
   - Marca e modello sono spesso stampati dentro, sul retro della cornetta o sulla scheda.
2. **Con il tester, mentre qualcuno suona dal portone,** cerca la coppia di morsetti su cui compare una **tensione alternata di 8–15 V**. Quelli sono **CA e 6**, cioè la chiamata e il comune.
3. **L'apriporta** è la coppia che, chiusa con un filo, fa scattare la serratura. Sul citofono originale sono i due contatti del pulsante a chiave. Su URMET sono **9 e 6**.
4. **La fonia** sono i due fili che vanno alla capsula (1) e al microfono (2) della cornetta del citofono originale.

Se i tuoi morsetti hanno nomi diversi, basta collegarli alle funzioni giuste su J5. Il firmware non cambia.

> Le misure prese direttamente sull'impianto sono più affidabili di qualsiasi identificazione fatta dalle foto: in fase di progetto l'impianto era stato scambiato per un Comelit, finché le misure non hanno dimostrato che era un URMET.

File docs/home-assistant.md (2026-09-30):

# Home Assistant, notifiche e assistenti vocali

La scheda usa ESPHome, quindi Home Assistant la trova da solo:

1. dopo il primo avvio compare in **Impostazioni → Dispositivi e servizi** come "Citofono Vintage";
2. clicca su **Configura**;
3. inserisci la chiave `api_encryption_key` che hai scritto in `secrets.yaml`.

## Entità disponibili

| Entità | Tipo | A cosa serve |
|---|---|---|
| **Apri portone** | pulsante | Apre il portone, con lo sgancio simulato se attivo |
| **Campanello** | evento (doorbell) | Tipo `chiamata` quando suonano, `apertura` quando si apre |
| **Chiamata in corso** | sensore binario | ON finché dura la chiamata |
| **Cornetta alzata** | sensore binario | |
| **Disco in rotazione** | sensore binario | |
| **Ultimo numero composto** | testo | Ultima cifra del disco |
| **Ultima chiamata / Ultima apertura** | testo | Data e ora |
| **Chiamate ricevute** | contatore | |
| **Non disturbare** | interruttore | Silenzia lo squillo |
| **Apertura automatica alla chiamata** | interruttore | Si spegne da sola al riavvio |
| **Apertura remota con sgancio simulato** | configurazione | Attiva K2 prima di aprire |
| **Rotella apre solo a cornetta alzata** | configurazione | |
| **Durata apertura portone** | configurazione | Da 300 a 4000 ms |
| **Codice rotella** | configurazione | Codice segreto (vuoto = qualsiasi numero apre) |
| **Test suoneria**, **Riavvia**, **Segnale WiFi**, **Uptime** | diagnostica | |

I nomi completi delle entità dipendono dal nome del dispositivo, per esempio `button.citofono_vintage_apri_portone`.

## Notifica con il pulsante "Apri"

Nel file [`home-assistant/automazioni-citofono.yaml`](../home-assistant/automazioni-citofono.yaml) ci sono due automazioni pronte:

1. **Notifica:** quando suonano, arriva sul telefono una notifica con il pulsante **"Apri il portone"**.
2. **Apertura:** toccando il pulsante nella notifica il portone si apre, e arriva la conferma "Portone aperto".

**Come usarle:**

1. Installa l'app **Home Assistant** sul telefono (iOS o Android) ed effettua l'accesso.
2. In Home Assistant: **Impostazioni → Automazioni → Crea automazione → ⋮ → Modifica in YAML**, e incolla una automazione alla volta.
3. Sostituisci `mobile_app_tuo_telefono` con il nome del tuo telefono. Lo trovi in **Strumenti per sviluppatori → Azioni**, cercando "notify.mobile_app".

## Google Home, Apple Home, Alexa

Si collegano **attraverso Home Assistant**. La scheda non deve fare nulla di speciale.

| Assistente | Integrazione di Home Assistant |
|---|---|
| Apple Home / Siri | **HomeKit Bridge** |
| Google Home | **Google Assistant**, tramite Home Assistant Cloud (Nabu Casa) o configurazione manuale |
| Alexa | **Amazon Alexa**, tramite Home Assistant Cloud o configurazione manuale |

Il modo più semplice e compatibile con tutti e tre:
1. crea in Home Assistant uno **script** "Apri portone" che preme il pulsante `button.citofono_vintage_apri_portone`;
2. esponi lo script all'assistente, che lo vede come una scena da attivare.

Per esempio: "Ok Google, attiva Apri portone".

> **Sicurezza:** uno script esposto come scena **non chiede conferme né PIN**: chiunque possa parlare all'assistente può aprire il portone. Valuta se esporlo, oppure esponi solo lo stato del campanello.

## Senza Home Assistant

La scheda ha una **pagina web locale** su `http://citofono-vintage.local`, oppure sull'indirizzo IP che le assegna il router.

- Si entra con utente `admin` e con la password `web_password` di `secrets.yaml`.
- Dalla pagina si possono aprire il portone, vedere lo stato e cambiare le impostazioni.

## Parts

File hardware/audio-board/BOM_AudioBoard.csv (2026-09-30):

Comment | Designator | Footprint | LCSC Part# | Qty | Note
1uF | C1,C2,C5,C8,C9,C10,C12,C13 | C_0603_1608Metric | C15849 | 8
10uF | C3,C14,C15 | C_0805_2012Metric | C15850 | 3
100nF | C4,C6,C7,C17 | C_0603_1608Metric | C14663 | 4
1uF 50V | C11 | C_1206_3216Metric |  | 1
2.2uF 50V | C16 | C_1206_3216Metric |  | 1
1N4148W | D1 | D_SOD-123 | C81598 | 1
LED blu AUDIO | D2 | LED_0805_2012Metric |  | 1
a J8 scheda madre | J1 | PinHeader_1x10_P2.54mm_Vertical |  | 1 | THT, saldatura a mano
a J9 (cornetta M R M/R) | J2 | PinHeader_1x03_P2.54mm_Vertical |  | 1 | THT, saldatura a mano
a J10 (linea 1 2) | J3 | PinHeader_1x02_P2.54mm_Vertical |  | 1 | THT, saldatura a mano
G5V-2-H1 DC5 | K1 | Relay_DPDT_Omron_G5V-2 | C28066 | 1 | THT, saldatura a mano
MMBT3904 | Q1 | SOT-23 | C20526 | 1
33 | R1 | R_0603_1608Metric |  | 1
4.7k | R2,R3,R10 | R_0603_1608Metric | C23162 | 3
2.2k | R4 | R_0603_1608Metric |  | 1
680 | R5 | R_0603_1608Metric |  | 1
470 | R6,R7 | R_0603_1608Metric |  | 2
1k | R8,R12 | R_0603_1608Metric | C21190 | 2
DNP 2.2k | R9 | R_0603_1608Metric |  | 1 | NON montare
100k | R11 | R_0603_1608Metric | C25803 | 1
SM-LP-5001 600:600 | T1,T2 | SM-LP-5001 | C7503474 | 2 | footprint da easyeda2kicad (vedi README)
ES8311 | U1 | QFN-20-1EP_3x3mm_P0.4mm_EP1.65x1.65mm | C962342 | 1
AP2112K-3.3 | U2 | SOT-23-5 | C51118 | 1
TCA9554PWR | U3 | TSSOP-16_4.4x5mm_P0.65mm | C477924 | 1

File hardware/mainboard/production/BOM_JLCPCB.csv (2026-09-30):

Reference | Qty | Value | LCSC Part# | DNP | Exclude from BOM | Exclude from Board | Footprint
BZ1 | 1 | TMB12A05 | C96093 |  |  |  | Buzzer_Beeper:Buzzer_12x9.5RM7.6
C1 | 1 | 100uF 50V | C97812 |  |  |  | Capacitor_SMD:CP_Elec_8x10
C2 | 1 | 2.2uF 100V | C577211 |  |  |  | Capacitor_SMD:C_1206_3216Metric
C3 | 1 | 2.2nF 50V | C1604 |  |  |  | Capacitor_SMD:C_0603_1608Metric
C4,C5 | 2 | 22uF 10V | C45783 |  |  |  | Capacitor_SMD:C_0805_2012Metric
C6,C7 | 2 | 10uF 10V | C15850 |  |  |  | Capacitor_SMD:C_0805_2012Metric
C8,C10,C11,C13 | 4 | 100nF | C14663 |  |  |  | Capacitor_SMD:C_0603_1608Metric
C9 | 1 | 470uF 10V | C970706 |  |  |  | Capacitor_SMD:CP_Elec_8x10
C12 | 1 | 4.7uF | C1779 |  |  |  | Capacitor_SMD:C_0805_2012Metric
C14 | 1 | 1uF | C15849 |  |  |  | Capacitor_SMD:C_0603_1608Metric
D1 | 1 | ABS10 1000V 0.8A | C400507 |  |  |  | Diode_SMD:Diode_Bridge_Diotec_ABS
D2 | 1 | SMAJ36A | C2760877 |  |  |  | Diode_SMD:D_SMA
D3,D4 | 2 | SS34 | C8678 |  |  |  | Diode_SMD:D_SMA
D5,D6 | 2 | 1N4148W | C81598 |  |  |  | Diode_SMD:D_SOD-123
D7 | 1 | LED verde | C2297 |  |  |  | LED_SMD:LED_0805_2012Metric
F1 | 1 | 0.5A 60V | C462518 |  |  |  | Fuse:Fuse_1812_4532Metric
J2 | 1 | USB-C | C165948 |  |  |  | Connector_USB:USB_C_Receptacle_HRO_TYPE-C-31-M-12
J3 | 1 | DISCO 1 2 3 4 |  |  |  |  | TerminalBlock_Phoenix:TerminalBlock_Phoenix_MKDS-1,5-4_1x04_P5.00mm_Horizontal
K1 | 1 | TLP3546A(F) o AQV252G |  |  |  |  | Package_DIP:DIP-6_W7.62mm
K2 | 1 | CPC1017N 60V 1A | C81521 |  |  |  | Package_SO:SOP-4_3.8x4.1mm_P2.54mm
L1 | 1 | 47uH 2A SRR1260-470M | C1329363 |  |  |  | Inductor_SMD:L_Bourns_SRR1260
OK1 | 1 | PC817 | C3025068 |  |  |  | Package_DIP:DIP-4_W7.62mm
Q1 | 1 | MMBT3904 | C20526 |  |  |  | Package_TO_SOT_SMD:SOT-23
R1,R4 | 2 | 100k | C25803 |  |  |  | Resistor_SMD:R_0603_1608Metric
R2 | 1 | 24.9k | C25962 |  |  |  | Resistor_SMD:R_0603_1608Metric
R3 | 1 | 49.9k | C23184 |  |  |  | Resistor_SMD:R_0603_1608Metric
R5 | 1 | 31.6k | C25967 |  |  |  | Resistor_SMD:R_0603_1608Metric
R6,R7 | 2 | 5.1k | C23186 |  |  |  | Resistor_SMD:R_0603_1608Metric
R8,R9,R10,R11,R12,R13 | 6 | 10k | C25804 |  |  |  | Resistor_SMD:R_0603_1608Metric
R14 | 1 | 15k 0.25W | C114932 |  |  |  | Resistor_SMD:R_1206_3216Metric
R15 | 1 | 390 | C23151 |  |  |  | Resistor_SMD:R_0603_1608Metric
R16 | 1 | 560 | C23204 |  |  |  | Resistor_SMD:R_0603_1608Metric
R17,R18 | 2 | 1k | C21190 |  |  |  | Resistor_SMD:R_0603_1608Metric
SW1 | 1 | RESET | C2886899 |  |  |  | Button_Switch_SMD:SW_SPST_TL3305A
SW2 | 1 | BOOT | C2886899 |  |  |  | Button_Switch_SMD:SW_SPST_TL3305A
U1 | 1 | LM5164DDA | C477928 |  |  |  | Package_SO:Texas_HSOP-8-1EP_3.9x4.9mm_P1.27mm
U2 | 1 | AMS1117-3.3 | C6186 |  |  |  | Package_TO_SOT_SMD:SOT-223-3_TabPin2
U3 | 1 | ESP32-S3-WROOM-1-N16R2 | C2913205 |  |  |  | RF_Module:ESP32-S3-WROOM-1

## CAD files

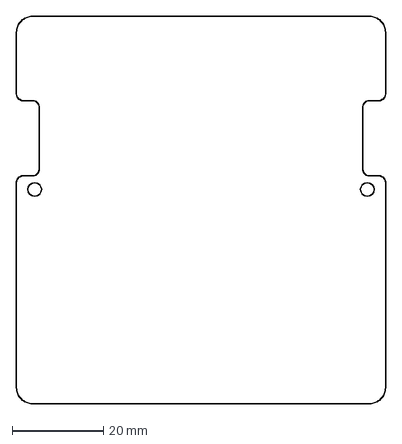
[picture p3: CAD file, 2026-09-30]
hardware/mechanical/S62_board_outline.dxf
81.0 x 85.0 mm

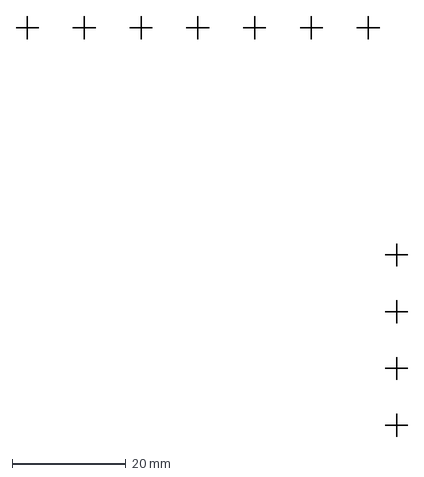
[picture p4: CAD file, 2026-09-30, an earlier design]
hardware/mechanical/S62_old_terminals_reference.dxf
69.0 x 74.0 mm

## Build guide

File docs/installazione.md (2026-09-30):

# Installazione nel telefono e collegamento al citofono

> Prima di tutto carica il firmware e fai le prove "da banco" del [collaudo](collaudo.md), passi 1–7, con la scheda **fuori dal telefono**. È molto più comodo trovare un problema adesso che dentro il guscio.

## Mappa dei morsetti

Mappa dei morsetti della scheda rev 0.5

| Morsetto | Pin | Collegamento |
|---|---|---|
| **J1** alimentazione | 1-2 | 9–36 V DC o 9–24 V AC, polarità indifferente |
| **J2** USB-C | | Programmazione, log e alimentazione a 5 V |
| **J3** disco | 1-2 | Contatto impulsi **cid**: chiuso a riposo, si apre a ogni impulso |
| | 3-4 | Contatto rotazione **cld**: chiuso mentre il disco torna indietro |
| **J4** cornetta e gancio | 1-2 | **HS2-HS1:** contatto del gancio usato per sapere se la cornetta è alzata |
| | 3 | **M/R:** filo comune della cornetta |
| | 4-5 | **HK1-HK2:** contatto del gancio che accende la fonia, chiuso a cornetta alzata |
| | 6 | **R:** capsula ricevente |
| | 7 | **M:** microfono |
| **J5** citofono | 1, 2, 6, 9, CA | Ai fili dell'impianto con lo stesso nome (vedi [compatibilità](compatibilita.md)) |
| **J6** suoneria (opz.) | 1-2 | Campanelli originali S62, attivi solo con JP3 chiuso |
| **J7** debug | TX, RX, GND | UART 3,3 V, facoltativo |
| **J8/J9/J10** | | Scheda audio (facoltativa) |

Il pin 1 di ogni connettore ha la **piazzola quadrata**. Guardando la scheda dal lato componenti con J4 e J5 in alto, il pin 1 di J1, J4 e J5 è a sinistra, mentre per J3 e J6 (sul lato destro) è quello più in basso.

## 1. Smontare il telefono

1. Svita la vite del guscio e sfila il coperchio.
2. **Fotografa tutto prima di staccare qualcosa:** quale filo va su quale morsetto e il colore dei fili del disco, del gancio e del cordone della cornetta.
3. Stacca i fili dalla vecchia morsettiera e svita la scheda originale. Conservala: se un giorno vuoi tornare indietro, tutto è reversibile.

## 2. Identificare i contatti con il tester

I colori dei fili variano fra un esemplare e l'altro, quindi conviene misurare con il tester in continuità (il "bip").

**Disco (4 fili):**
- **cid** è la coppia **chiusa a riposo** che "sfarfalla" (apre e chiude) mentre il disco torna indietro. Va su **J3 1-2**.
- **cld** è la coppia **aperta a riposo** che si chiude appena giri il disco e si riapre quando è tornato a riposo. Va su **J3 3-4**.
- J3 1 e J3 3 sono entrambi a massa. Se un filo è in comune fra i due contatti, mettilo su 1 e ponticella 1 con 3.

**Gancio:** il commutatore del gancio ha diversi contatti. Servono due contatti **che si chiudono quando la cornetta è alzata** e che non abbiano fili in comune fra loro:
- il primo va su **J4 4-5** (HK1-HK2) e accende la fonia;
- il secondo va su **J4 1-2** (HS2-HS1) e informa l'ESP32.

  Se il secondo contatto disponibile è invece **aperto** a cornetta alzata, va bene lo stesso: al collaudo si inverte la logica nel firmware con una riga (`inverted`).

**Cornetta (cordone a 3 fili):**
- il filo **comune** va su **J4 3** (M/R);
- la **capsula** va su **J4 6** (R);
- il **microfono** va su **J4 7** (M).

Per distinguerli: la capsula ha una resistenza bassa, qualche decina o centinaio di ohm, fra il suo filo e il comune.

## 3. Montare la scheda

1. Avvita la scheda sui due perni originali con le viti originali (fori Ø 3 mm).
2. Collega disco, gancio e cornetta come identificato sopra. Spella circa 6 mm. Se i fili sono a trecciola molto sottile, stagnali prima o usa i puntalini.
3. Fai passare i fili dell'impianto e dell'alimentazione dal passacavo originale.

## 4. Alimentazione

Il citofono 4+N non alimenta il posto interno. Ci sono tre possibilità:

| Soluzione | Quando conviene |
|---|---|
| **Alimentatore 12 V DC da 1 A** su J1 | Soluzione tipica: una presa vicina e due fili in più nel tubo del citofono |
| **12 V AC** dal trasformatore dell'impianto su J1 | Solo se i morsetti del trasformatore sono raggiungibili e hai il permesso di usarli |
| **Caricatore USB-C 5 V** | Il più semplice, anche per l'uso quotidiano, ma serve un cavo USB che esca dal telefono |

## 5. Collegare il citofono (J5)

1. **Stacca l'alimentazione della scheda.**
2. Identifica i fili dell'impianto come spiegato in [compatibilità](compatibilita.md).
3. Collega **1, 2, 6, 9, CA** agli stessi morsetti di J5.
4. Richiudi il telefono solo dopo aver fatto i passi 8–11 del [collaudo](collaudo.md).

## 6. Ponticelli

| Ponticello | Di fabbrica | Quando cambiarlo |
|---|---|---|
| **JP1**: linea 1 ↔ capsula | chiuso | Si taglia solo se monti la scheda audio |
| **JP2**: linea 2 ↔ microfono | chiuso | Si taglia solo se monti la scheda audio |
| **JP3**: suoneria J6 ↔ CA | aperto | Si chiude con una goccia di stagno per provare i campanelli originali |

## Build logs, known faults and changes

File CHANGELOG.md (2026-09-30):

# Changelog

## Scheda principale

### rev 0.5 (settembre 2026): primi prototipi
- Ordinati 5 prototipi assemblati da JLCPCB (29/09/2026). **Collaudo in corso.**
- Modulo ESP32-S3-WROOM-1-**N16R2** (PSRAM quad).
- K1: PhotoMOS DIP-6 a foro passante, TLP3546A(F) o AQV252G, da saldare a mano.
- Codici LCSC su tutti i componenti assemblati.
- Posizionamento dei componenti rivisto e sbroglio completo. DRC: 0 connessioni mancanti, 0 violazioni elettriche.

### rev 0.3 (settembre 2026)
- Schema completo: alimentazione con LM5164 (sostituisce l'LM5165, limitato a 150 mA), interfaccia URMET isolata (PC817, due PhotoMOS), interfaccia S62, ESP32-S3.
- Ordine dei pin di J4 cambiato per far passare la barriera di isolamento: `1=HS2 2=HS1 3=M/R 4=HK1 5=HK2 6=R 7=M`.
- Barriera di isolamento a strisce su entrambi gli strati; J8 spostato sul bordo sinistro.

## Firmware

### 0.5.0 (settembre 2026)
- Prima versione ESPHome, con queste funzioni:
  - apertura con il disco, con codice segreto opzionale;
  - apertura remota con sgancio simulato;
  - rilevamento della chiamata con squillo, evento campanello e storico;
  - "Non disturbare" e apertura automatica;
  - pagina web locale;
  - sicurezze sui relè.
- Pacchetto opzionale `audio-es8311.yaml` per la scheda audio.

## Scheda audio

### rev 0.1 (settembre 2026)
- Schema con codec ES8311, trasformatori di isolamento 600:600, relè fail-safe ed espansore I2C TCA9554. PCB non ancora disegnato.

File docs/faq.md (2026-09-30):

# Domande frequenti

**Il telefono funziona ancora come citofono se il WiFi non c'è o Home Assistant è spento?**
Sì. Squillo, apertura con il disco e conversazione con la cornetta funzionano in locale. Il WiFi serve solo per notifiche, apertura remota e storico.

**E se la scheda è spenta o guasta?**
La conversazione funziona lo stesso: l'audio passa in analogico dai ponticelli JP1/JP2 e il gancio accende la fonia come nel citofono originale. Non si sente la chiamata e non si apre il portone finché la scheda non torna in funzione.

**La scheda registra o trasmette l'audio?**
No. Nella scheda principale l'audio passa in analogico e l'ESP32 non lo riceve. Ascolto e risposta da remoto richiedono la [scheda audio](../hardware/audio-board/README.md), ancora in sviluppo, e saranno sempre funzioni da attivare esplicitamente.

**Posso usarla con un citofono di un'altra marca?**
Se è un 4+N analogico, probabilmente sì, ma serve identificare i morsetti con il tester. Vedi [compatibilità](compatibilita.md).

**Serve per forza un alimentatore?**
Sì. Il citofono 4+N non alimenta il posto interno: la tensione sulla linea di chiamata c'è solo mentre qualcuno suona. Si può usare un alimentatore 12 V su J1 oppure un caricatore USB-C da 5 V.

**Suonano i campanelli originali dell'S62?**
Di serie suona il buzzer della scheda. I campanelli originali si possono collegare a J6 chiudendo JP3, ma è sperimentale: servono molta più potenza di quella che molti impianti danno sulla linea di chiamata.

**Posso aprire il portone con un codice invece che con un numero qualsiasi?**
Sì: imposta il "Codice rotella" (fino a 8 cifre) da Home Assistant o dalla pagina web.

**Posso comprare la scheda già fatta?**
Per ora no: il progetto è solo fai-da-te e si ordina da JLCPCB con i file della repository. Se ci sarà interesse, potrebbe arrivare una versione più economica già pronta.

**Posso modificare il progetto e venderlo?**
Sì, rispettando le [licenze](../LICENSE.md). L'hardware è CERN-OHL-S: chi distribuisce schede modificate deve pubblicare anche i sorgenti delle modifiche con la stessa licenza.

**Il guscio o il telefono vengono modificati?**
No. La scheda sostituisce quella originale sugli stessi supporti e con le stesse viti. Conserva la scheda originale: l'operazione è reversibile.

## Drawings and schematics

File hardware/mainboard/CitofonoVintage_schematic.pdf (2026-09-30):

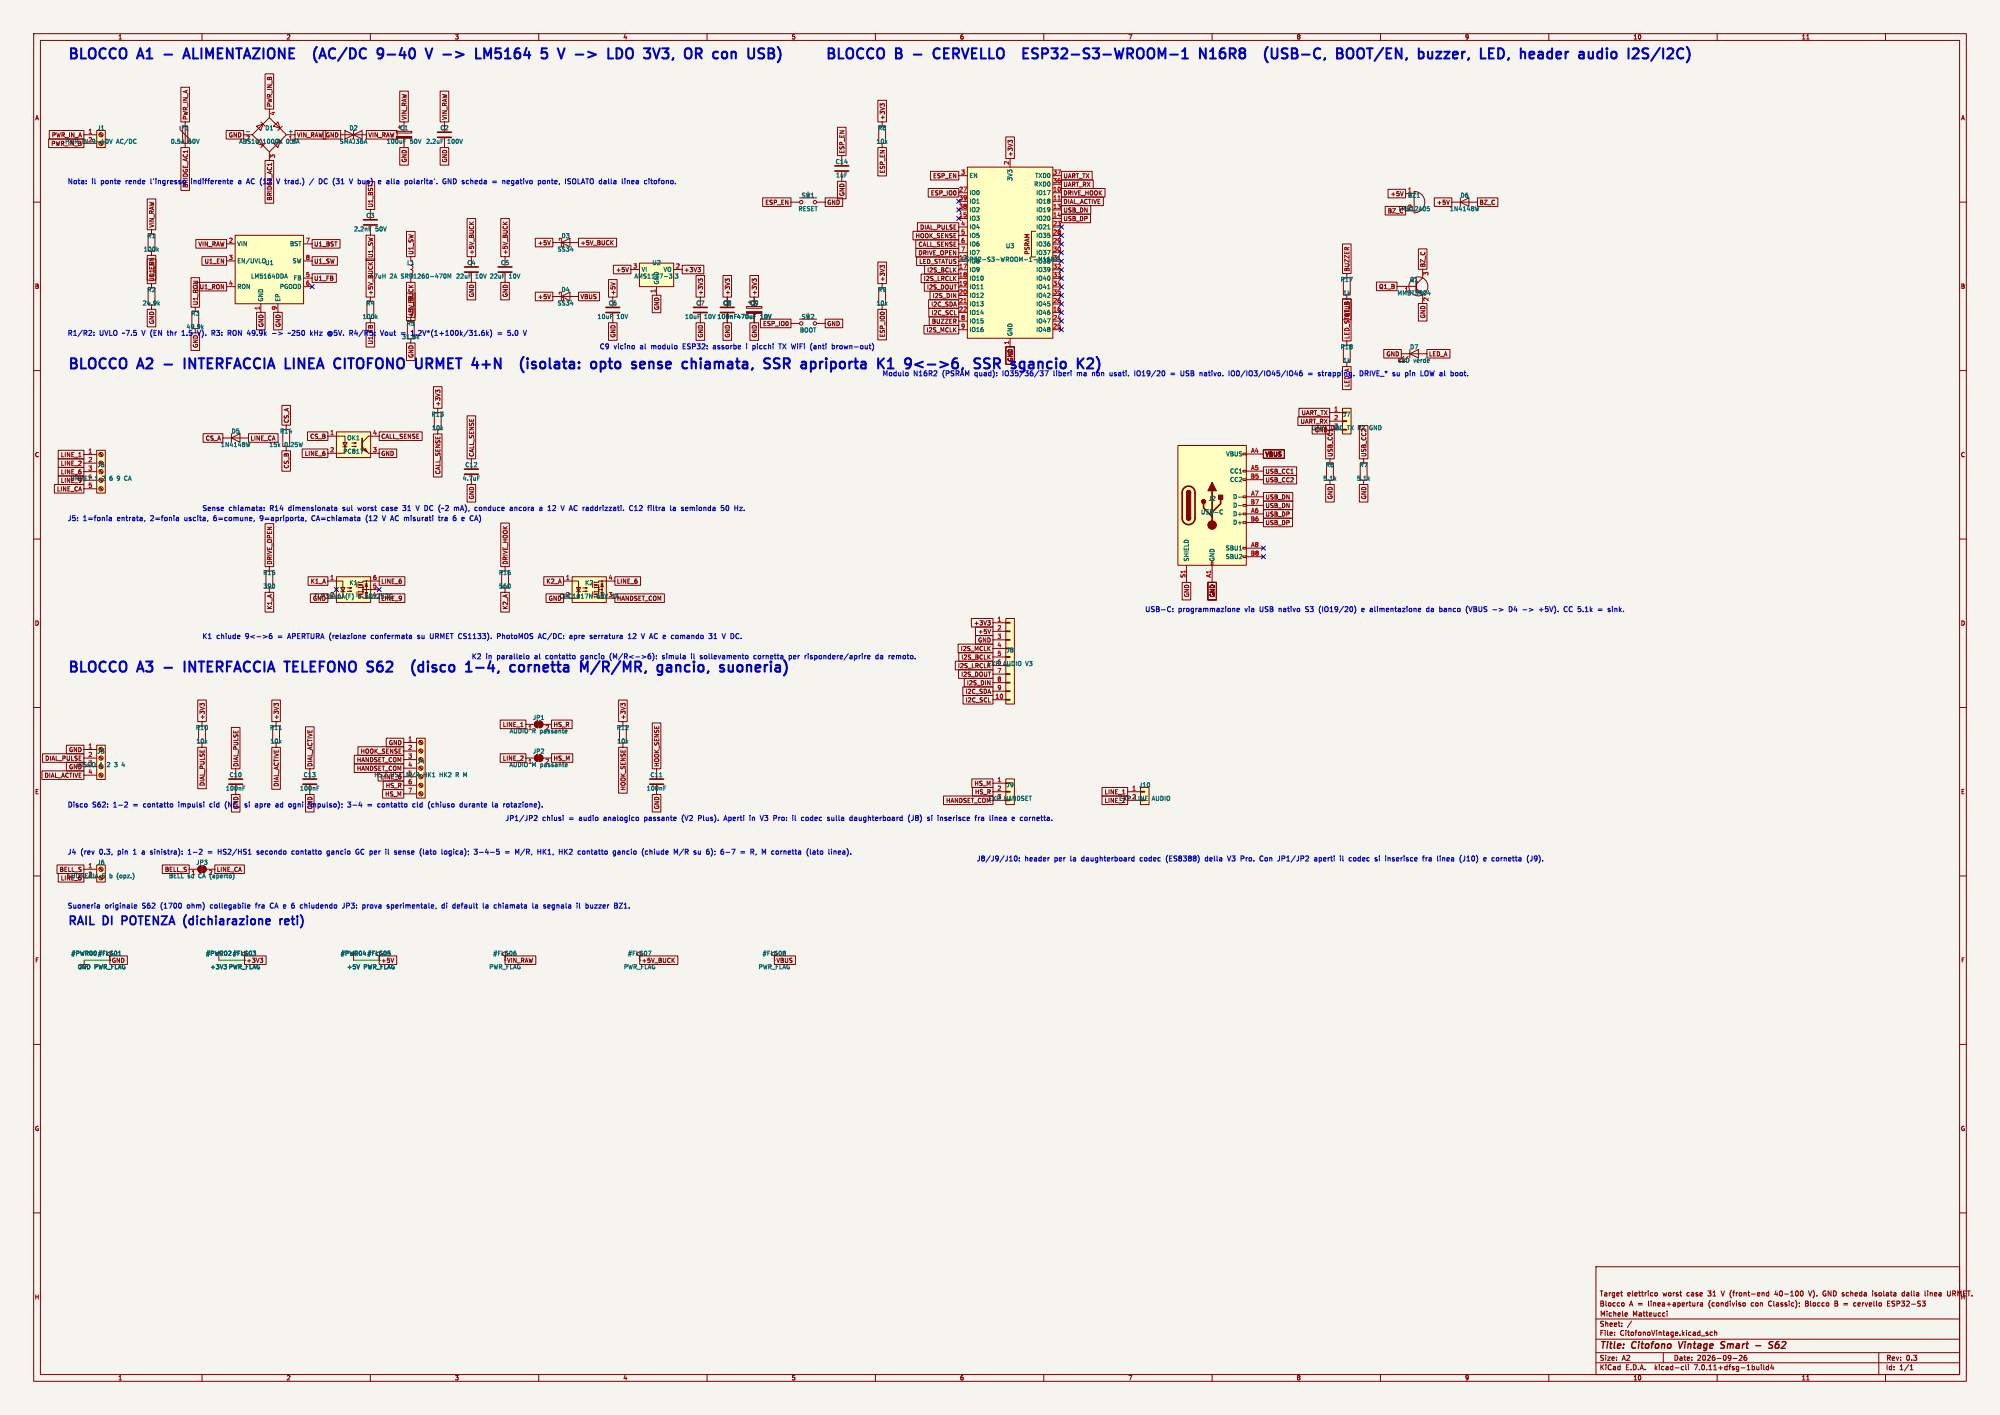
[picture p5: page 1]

1 VIN 2 EN/UVLO 3 RON 4 FB 5 PGOOD 6 BST 7 SW 8 EP

J7 UART DBG TX RX GND

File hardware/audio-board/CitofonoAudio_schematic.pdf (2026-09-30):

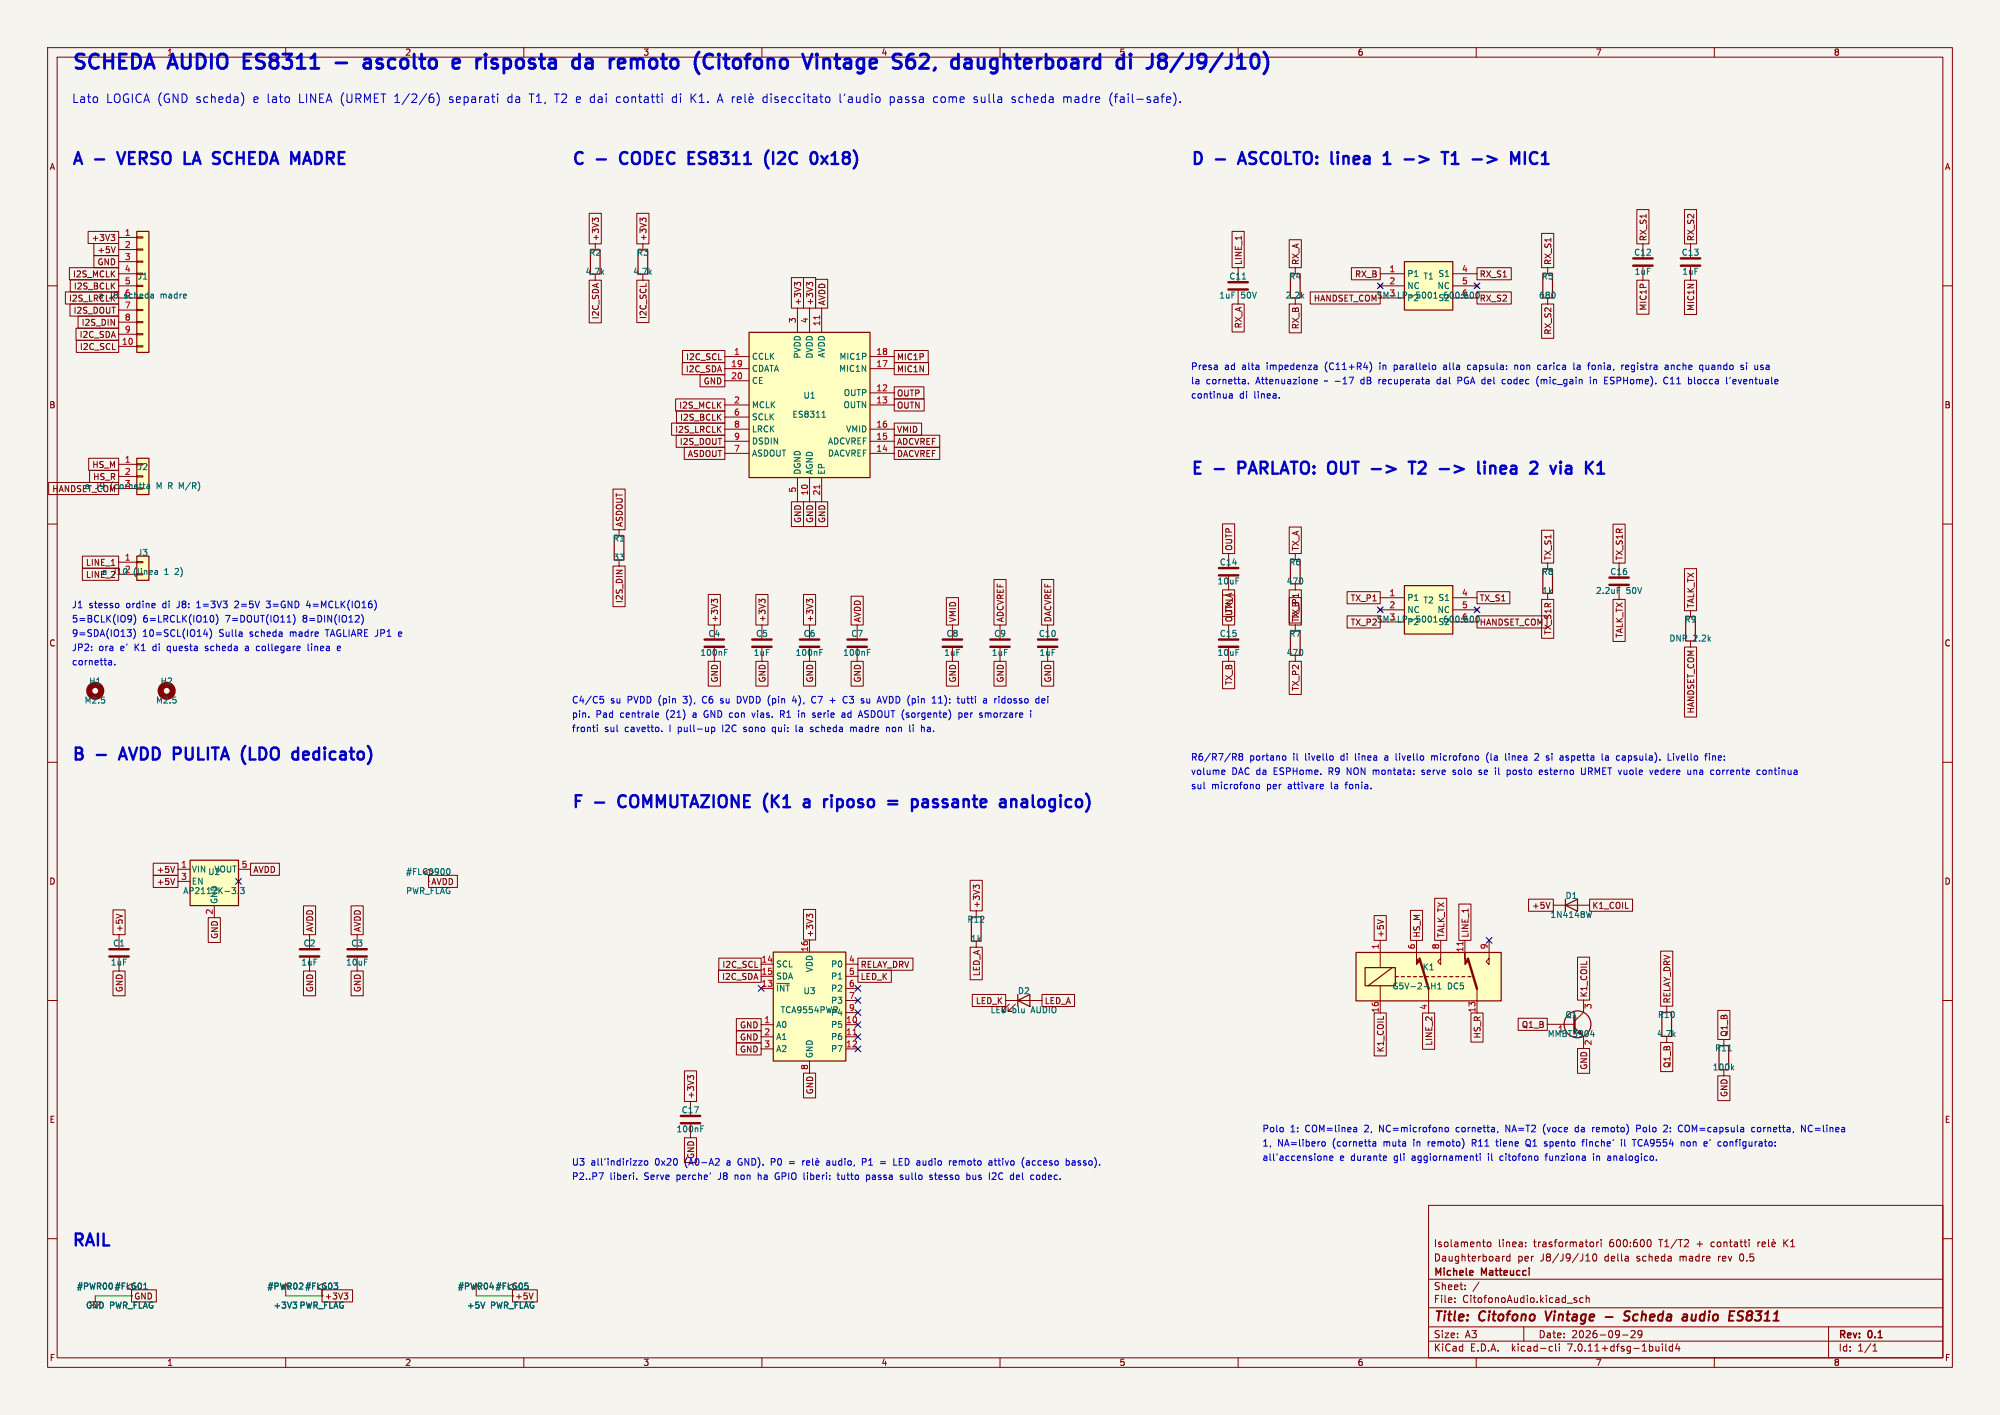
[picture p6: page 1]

A - VERSO LA SCHEDA MADRE

B - AVDD PULITA (LDO dedicato)

Id: 1/1 Title: Citofono Vintage - Scheda audio ES8311

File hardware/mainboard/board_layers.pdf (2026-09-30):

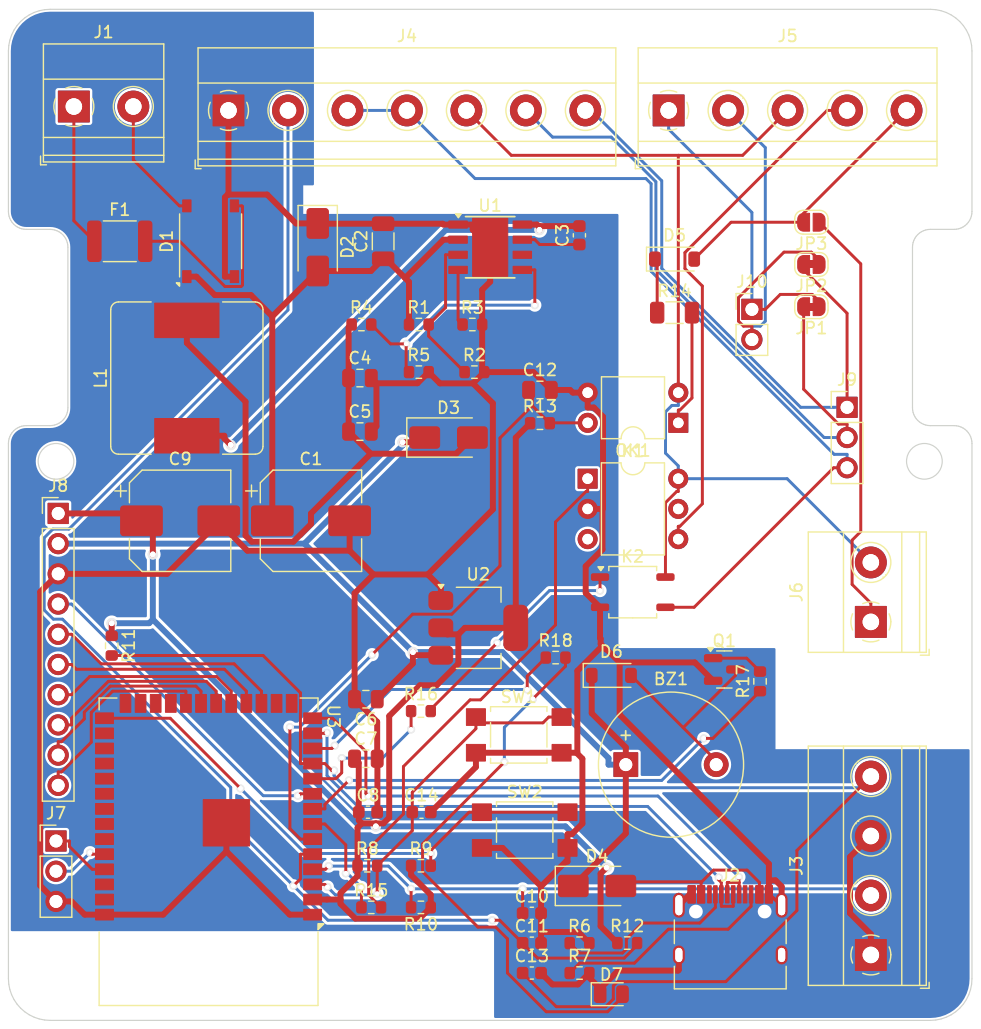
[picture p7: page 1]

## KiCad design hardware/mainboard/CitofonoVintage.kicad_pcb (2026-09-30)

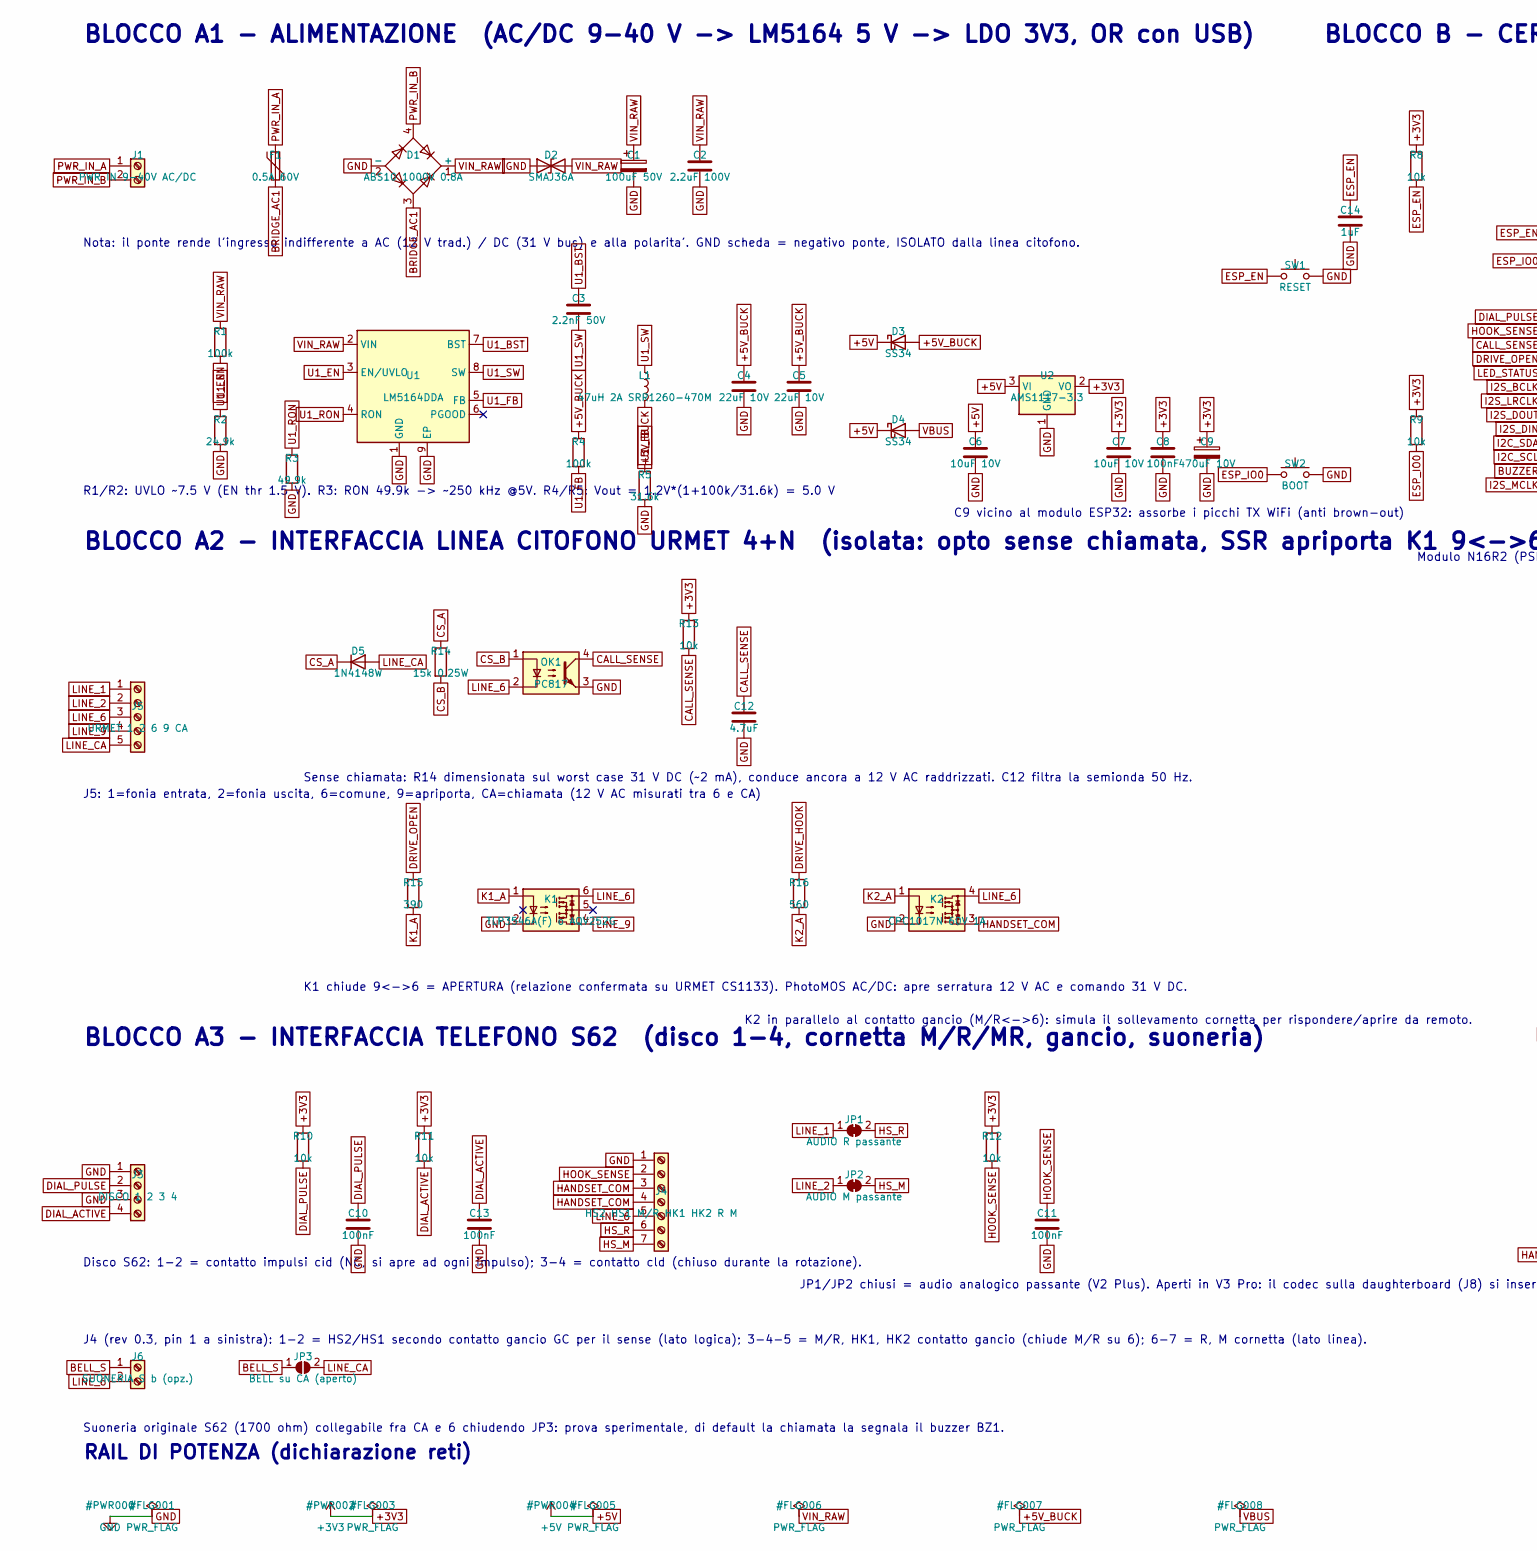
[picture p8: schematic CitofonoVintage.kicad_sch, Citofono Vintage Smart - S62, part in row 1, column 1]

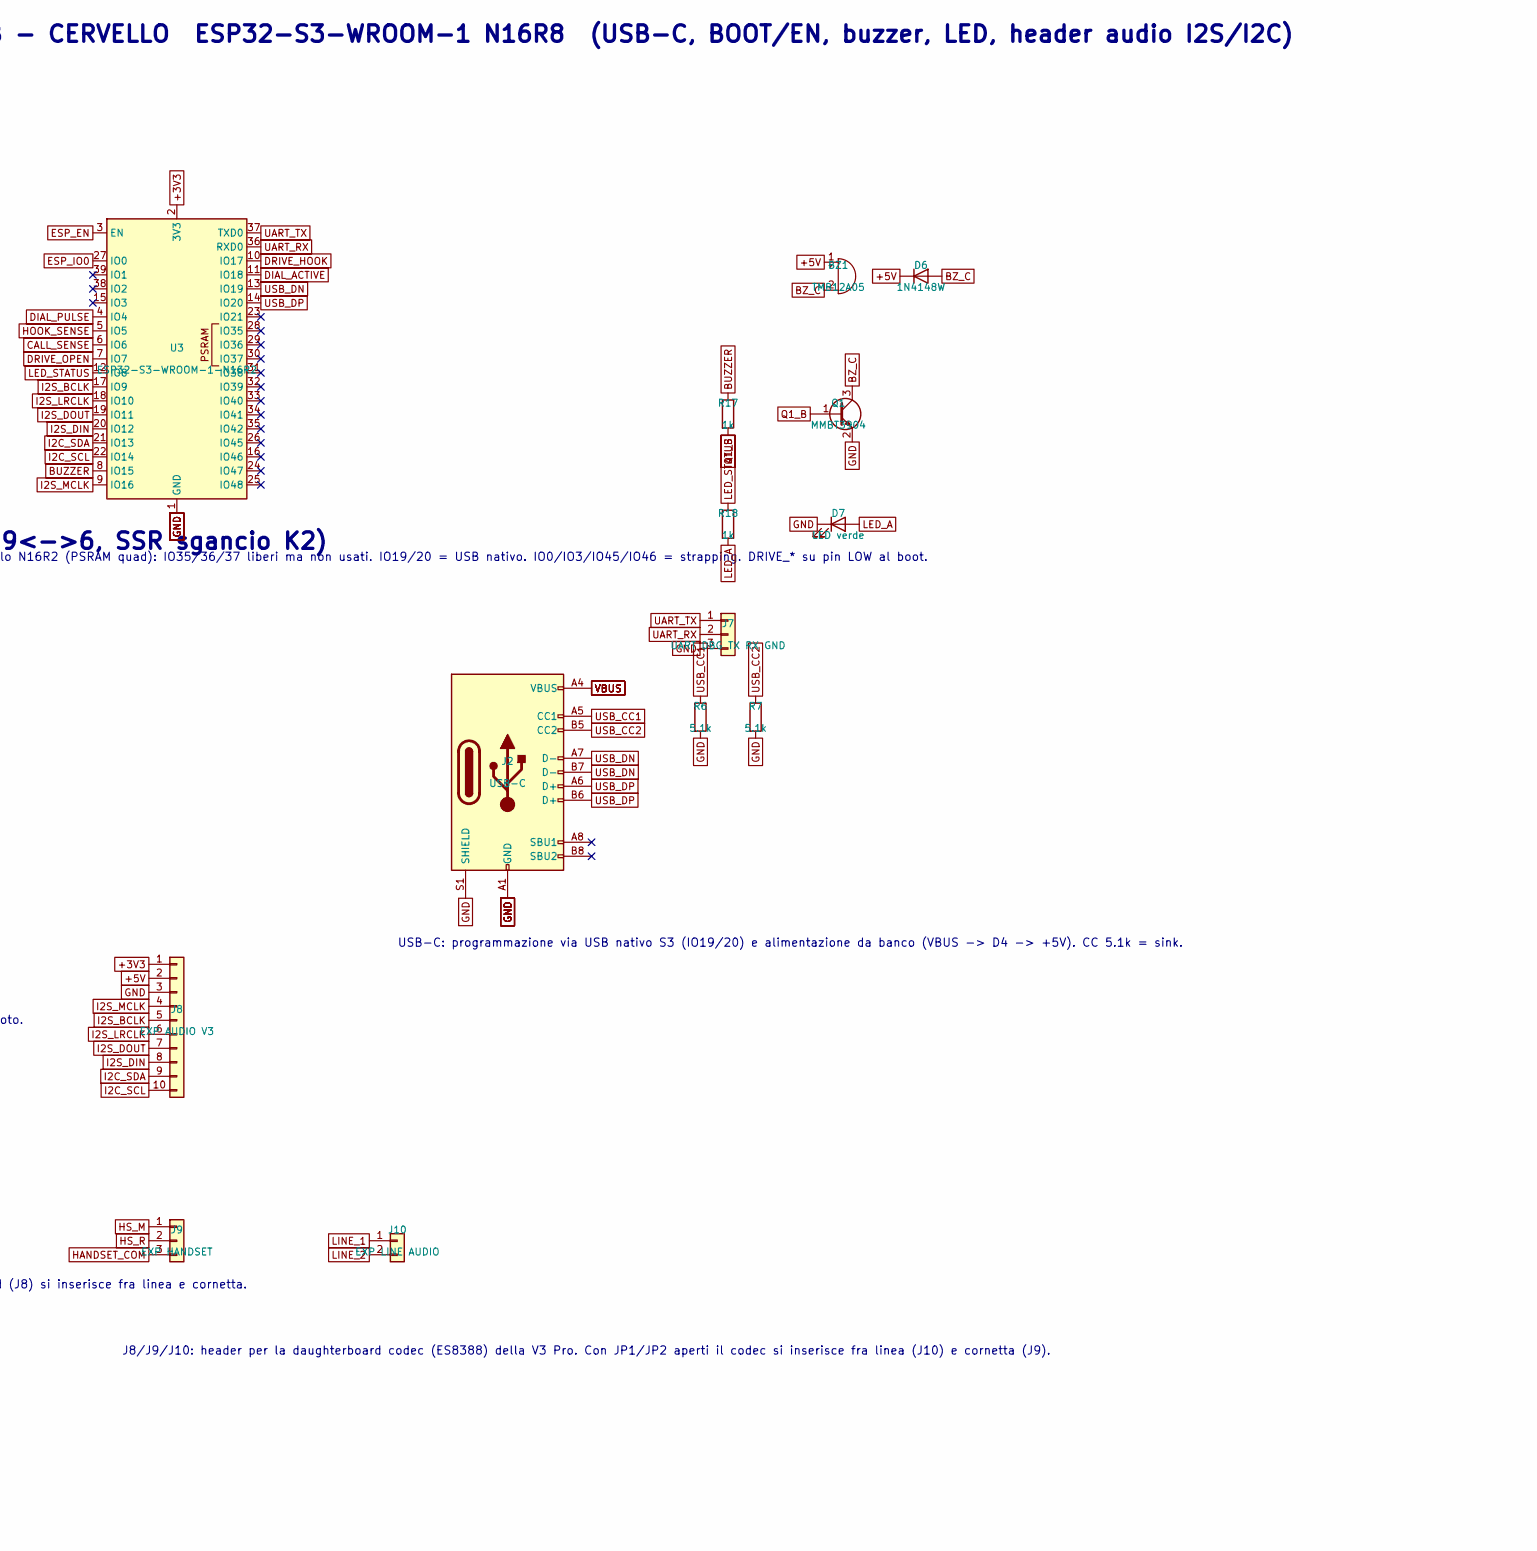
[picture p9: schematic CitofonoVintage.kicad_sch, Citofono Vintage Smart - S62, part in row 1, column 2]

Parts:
BZ1: TMB12A05; Buzzer_12x9.5RM7.6; LCSC Part# C96093
C1: 100uF 50V; CP_Elec_8x10; LCSC Part# C97812
C2: 2.2uF 100V; C_1206_3216Metric; LCSC Part# C577211
C3: 2.2nF 50V; C_0603_1608Metric; LCSC Part# C1604
C4, C5: 22uF 10V; C_0805_2012Metric; LCSC Part# C45783
C6, C7: 10uF 10V; C_0805_2012Metric; LCSC Part# C15850
C8, C10, C11, C13: 100nF; C_0603_1608Metric; LCSC Part# C14663
C9: 470uF 10V; CP_Elec_8x10; LCSC Part# C970706
C12: 4.7uF; C_0805_2012Metric; LCSC Part# C1779
C14: 1uF; C_0603_1608Metric; LCSC Part# C15849
D1: ABS10 1000V 0.8A; Diode_Bridge_Diotec_ABS; LCSC Part# C400507
D2: SMAJ36A; D_SMA; LCSC Part# C2760877
D3, D4: SS34; D_SMA; LCSC Part# C8678
D5, D6: 1N4148W; D_SOD-123; LCSC Part# C81598
D7: LED verde; LED_0805_2012Metric; LCSC Part# C2297
F1: 0.5A 60V; Fuse_1812_4532Metric; LCSC Part# C462518
J1: PWR IN 9-40V AC/DC; TerminalBlock_Phoenix_MKDS-1,5-2_1x02_P5.00mm_Horizontal
J2: USB-C; USB_C_Receptacle_HRO_TYPE-C-31-M-12; LCSC Part# C165948
J3: DISCO 1 2 3 4; TerminalBlock_Phoenix_MKDS-1,5-4_1x04_P5.00mm_Horizontal
J4: HS2 HS1 M/R HK1 HK2 R M; TerminalBlock_Phoenix_MKDS-1,5-7_1x07_P5.00mm_Horizontal
J5: URMET 1 2 6 9 CA; TerminalBlock_Phoenix_MKDS-1,5-5_1x05_P5.00mm_Horizontal
J6: SUONERIA S b (opz.); TerminalBlock_Phoenix_MKDS-1,5-2_1x02_P5.00mm_Horizontal
J7: UART DBG TX RX GND; PinHeader_1x03_P2.54mm_Vertical
J8: EXP AUDIO V3; PinHeader_1x10_P2.54mm_Vertical
J9: EXP HANDSET; PinHeader_1x03_P2.54mm_Vertical
J10: EXP LINE AUDIO; PinHeader_1x02_P2.54mm_Vertical
JP1: AUDIO R passante; SolderJumper-2_P1.3mm_Bridged_RoundedPad1.0x1.5mm
JP2: AUDIO M passante; SolderJumper-2_P1.3mm_Bridged_RoundedPad1.0x1.5mm
JP3: BELL su CA (aperto); SolderJumper-2_P1.3mm_Open_RoundedPad1.0x1.5mm
K1: TLP3546A(F) o AQV252G; DIP-6_W7.62mm
K2: CPC1017N 60V 1A; SOP-4_3.8x4.1mm_P2.54mm; LCSC Part# C81521
L1: 47uH 2A SRR1260-470M; L_Bourns_SRR1260; LCSC Part# C1329363
OK1: PC817; DIP-4_W7.62mm; LCSC Part# C3025068
Q1: MMBT3904; SOT-23; LCSC Part# C20526
R1, R4: 100k; R_0603_1608Metric; LCSC Part# C25803
R2: 24.9k; R_0603_1608Metric; LCSC Part# C25962
R3: 49.9k; R_0603_1608Metric; LCSC Part# C23184
R5: 31.6k; R_0603_1608Metric; LCSC Part# C25967
R6, R7: 5.1k; R_0603_1608Metric; LCSC Part# C23186
R8, R9, R10, R11, R12, R13: 10k; R_0603_1608Metric; LCSC Part# C25804
R14: 15k 0.25W; R_1206_3216Metric; LCSC Part# C114932
R15: 390; R_0603_1608Metric; LCSC Part# C23151
R16: 560; R_0603_1608Metric; LCSC Part# C23204
R17, R18: 1k; R_0603_1608Metric; LCSC Part# C21190
SW1: RESET; SW_SPST_TL3305A; LCSC Part# C2886899
SW2: BOOT; SW_SPST_TL3305A; LCSC Part# C2886899
U1: LM5164DDA; Texas_HSOP-8-1EP_3.9x4.9mm_P1.27mm; LCSC Part# C477928
U2: AMS1117-3.3; SOT-223-3_TabPin2; LCSC Part# C6186
U3: ESP32-S3-WROOM-1-N16R2; ESP32-S3-WROOM-1; LCSC Part# C2913205

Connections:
+3V3: C7.1, C8.1, C9.1, J8.1, R8.1, R9.1, R10.1, R11.1, R12.1, R13.1, U2.2 (VO), U3.2 (3V3)
+5V: BZ1.1 (+), C6.1, D3.1 (K), D4.1 (K), D6.1 (K), J8.2, U2.3 (VI)
+5V_BUCK: C4.1, C5.1, D3.2 (A), L1.2, R4.1
BELL_S: J6.1, JP3.1 (A)
BRIDGE_AC1: D1.3, F1.2
BUZZER: R17.1, U3.8 (IO15)
BZ_C: BZ1.2 (-), D6.2 (A), Q1.3 (C)
CALL_SENSE: C12.1, OK1.4, R13.2, U3.6 (IO6)
CS_A: D5.1 (K), R14.1
CS_B: OK1.1, R14.2
DIAL_ACTIVE: C13.1, J3.4, R11.2, U3.11 (IO18)
DIAL_PULSE: C10.1, J3.2, R10.2, U3.4 (IO4)
DRIVE_HOOK: R16.1, U3.10 (IO17)
DRIVE_OPEN: R15.1, U3.7 (IO7)
ESP_EN: C14.1, R8.2, SW1.1, U3.3 (EN)
ESP_IO0: R9.2, SW2.1, U3.27 (IO0)
GND: C1.2, C2.2, C4.2, C5.2, C6.2, C7.2, C8.2, C9.2, C10.2, C11.2, C12.2, C13.2, C14.2, D1.2 (-), D2.1 (A1), D7.1 (K), J2.A1 (GND), J2.A12 (GND), J2.B1 (GND), J2.B12 (GND), J2.S1 (SHIELD), J3.1, J3.3, J4.1, J7.3, J8.3, K1.2, K2.2, OK1.3, Q1.2 (E), R2.2, R3.2, R5.2, R6.2, R7.2, SW1.2, SW2.2, U1.1 (GND), U1.9 (EP), U2.1 (GND), U3.1 (GND), U3.40 (GND), U3.41 (GND)
HANDSET_COM: J4.3, J4.4, J9.3, K2.3
HOOK_SENSE: C11.1, J4.2, R12.2, U3.5 (IO5)
HS_M: J4.7, J9.1, JP2.2 (B)
HS_R: J4.6, J9.2, JP1.2 (B)
I2C_SCL: J8.10, U3.22 (IO14)
I2C_SDA: J8.9, U3.21 (IO13)
I2S_BCLK: J8.5, U3.17 (IO9)
I2S_DIN: J8.8, U3.20 (IO12)
I2S_DOUT: J8.7, U3.19 (IO11)
I2S_LRCLK: J8.6, U3.18 (IO10)
I2S_MCLK: J8.4, U3.9 (IO16)
K1_A: K1.1, R15.2
K2_A: K2.1, R16.2
LED_A: D7.2 (A), R18.2
LED_STATUS: R18.1, U3.12 (IO8)
LINE_1: J5.1, J10.1, JP1.1 (A)
LINE_2: J5.2, J10.2, JP2.1 (A)
LINE_6: J4.5, J5.3, J6.2, K1.6, K2.4, OK1.2
LINE_9: J5.4, K1.4
LINE_CA: D5.2 (A), J5.5, JP3.2 (B)
PWR_IN_A: F1.1, J1.1
PWR_IN_B: D1.4, J1.2
Q1_B: Q1.1 (B), R17.2
U1_BST: C3.1, U1.7 (BST)
U1_EN: R1.2, R2.1, U1.3 (EN/UVLO)
U1_FB: R4.2, R5.1, U1.5 (FB)
U1_RON: R3.1, U1.4 (RON)
U1_SW: C3.2, L1.1, U1.8 (SW)
UART_RX: J7.2, U3.36 (RXD0)
UART_TX: J7.1, U3.37 (TXD0)
USB_CC1: J2.A5 (CC1), R6.1
USB_CC2: J2.B5 (CC2), R7.1
USB_DN: J2.A7 (D-), J2.B7 (D-), U3.13 (IO19)
USB_DP: J2.A6 (D+), J2.B6 (D+), U3.14 (IO20)
VBUS: D4.2 (A), J2.A4 (VBUS), J2.A9 (VBUS), J2.B4 (VBUS), J2.B9 (VBUS)
VIN_RAW: C1.1, C2.1, D1.1 (+), D2.2 (A2), R1.1, U1.2 (VIN)

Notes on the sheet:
Disco S62: 1-2 = contatto impulsi cid (NC, si apre ad ogni impulso); 3-4 = contatto cld (chiuso durante la rotazione).
J5: 1=fonia entrata, 2=fonia uscita, 6=comune, 9=apriporta, CA=chiamata (12 V AC misurati tra 6 e CA)
J8/J9/J10: header per la daughterboard codec (ES8388) della V3 Pro. Con JP1/JP2 aperti il codec si inserisce fra linea (J10) e cornetta (J9).
JP1/JP2 chiusi = audio analogico passante (V2 Plus). Aperti in V3 Pro: il codec sulla daughterboard (J8) si inserisce fra linea e cornetta.
USB-C: programmazione via USB nativo S3 (IO19/20) e alimentazione da banco (VBUS -> D4 -> +5V). CC 5.1k = sink.
Sense chiamata: R14 dimensionata sul worst case 31 V DC (~2 mA), conduce ancora a 12 V AC raddrizzati. C12 filtra la semionda 50 Hz.
R1/R2: UVLO ~7.5 V (EN thr 1.5 V). R3: RON 49.9k -> ~250 kHz @5V. R4/R5: Vout = 1.2V*(1+100k/31.6k) = 5.0 V
J4 (rev 0.3, pin 1 a sinistra): 1-2 = HS2/HS1 secondo contatto gancio GC per il sense (lato logica); 3-4-5 = M/R, HK1, HK2 contatto gancio (chiude M/R su 6); 6-7 = R, M cornetta (lato linea).
K2 in parallelo al contatto gancio (M/R<->6): simula il sollevamento cornetta per rispondere/aprire da remoto.
BLOCCO A2 - INTERFACCIA LINEA CITOFONO URMET 4+N (isolata: opto sense chiamata, SSR apriporta K1 9<->6, SSR sgancio K2)
Suoneria originale S62 (1700 ohm) collegabile fra CA e 6 chiudendo JP3: prova sperimentale, di default la chiamata la segnala il buzzer BZ1.
Nota: il ponte rende l'ingresso indifferente a AC (12 V trad.) / DC (31 V bus) e alla polarita'. GND scheda = negativo ponte, ISOLATO dalla linea citofono.
C9 vicino al modulo ESP32: assorbe i picchi TX WiFi (anti brown-out)
RAIL DI POTENZA (dichiarazione reti)
K1 chiude 9<->6 = APERTURA (relazione confermata su URMET CS1133). PhotoMOS AC/DC: apre serratura 12 V AC e comando 31 V DC.
BLOCCO B - CERVELLO ESP32-S3-WROOM-1 N16R8 (USB-C, BOOT/EN, buzzer, LED, header audio I2S/I2C)
BLOCCO A1 - ALIMENTAZIONE (AC/DC 9-40 V -> LM5164 5 V -> LDO 3V3, OR con USB)
Modulo N16R2 (PSRAM quad): IO35/36/37 liberi ma non usati. IO19/20 = USB nativo. IO0/IO3/IO45/IO46 = strapping. DRIVE_* su pin LOW al boot.
BLOCCO A3 - INTERFACCIA TELEFONO S62 (disco 1-4, cornetta M/R/MR, gancio, suoneria)

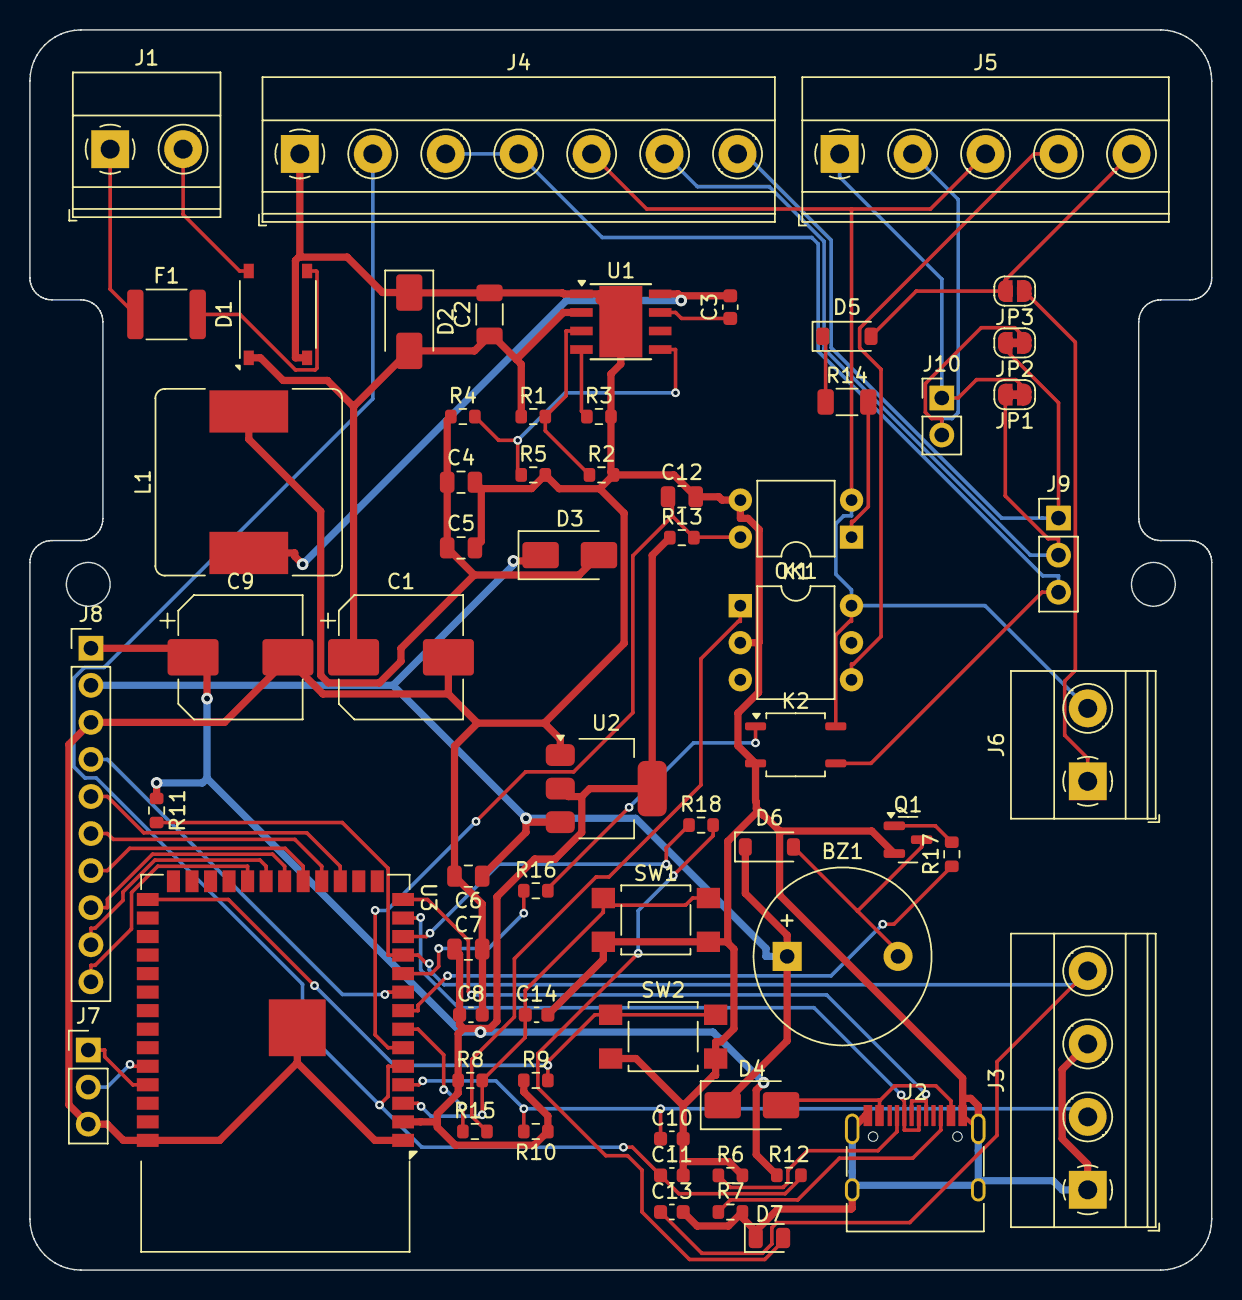
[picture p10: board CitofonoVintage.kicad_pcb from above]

Board: 2 copper layers, 81.0 x 85.0 mm, 64 parts (0 on the bottom side), 53 nets.

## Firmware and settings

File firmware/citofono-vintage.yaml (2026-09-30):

# =============================================================================
#  Citofono Vintage — firmware ESPHome per la scheda rev 0.5 (Siemens S62 / URMET 4+N)
#
#  Mappa GPIO (da schematic rev 0.3+):
#    IO4  DIAL_PULSE   disco 1-2, contatto impulsi cid (chiuso a riposo -> LOW, ogni impulso -> HIGH)
#    IO18 DIAL_ACTIVE  disco 3-4, contatto cld (chiuso durante la rotazione -> LOW)
#    IO5  HOOK_SENSE   cornetta: contatto gancio HS1-HS2 su J4 pin 1-2
#    IO6  CALL_SENSE   optoisolatore OK1: LOW quando arriva la chiamata (12 V AC su CA)
#    IO7  DRIVE_OPEN   K1 -> chiude 9<->6 = APRE IL PORTONE
#    IO17 DRIVE_HOOK   K2 -> simula il sollevamento della cornetta (abilita la fonia URMET)
#    IO15 BUZZER       Q1 -> buzzer attivo TMB12A05
#    IO8  LED_STATUS   LED verde D7
#    IO19/IO20         USB nativo (programmazione e log)
#
#  Primo caricamento: via USB-C con il cavo, poi aggiornamenti via WiFi (OTA).
# =============================================================================

substitutions:
  name: citofono-vintage
  friendly_name: Citofono Vintage
  # Durata della chiusura del relè apriporta (ms). Modificabile anche da Home Assistant.
  open_time_default: "1500"
  # Pausa tra "sgancio simulato" e apertura, nell'apertura remota (ms)
  hook_settle_ms: "400"

esphome:
  name: ${name}
  friendly_name: ${friendly_name}
  project:
    name: "citofono-vintage.s62"
    version: "0.5.0"
  on_boot:
    priority: -100
    then:
      # Sicurezza: all'avvio i due relè devono essere sempre aperti
      - switch.turn_off: relay_open
      - switch.turn_off: relay_hook

esp32:
  board: esp32-s3-devkitc-1
  variant: esp32s3
  flash_size: 16MB
  framework:
    type: esp-idf

# Modulo ESP32-S3-WROOM-1-N16R2: PSRAM quad da 2 MB
psram:
  mode: quad
  speed: 80MHz

logger:
  hardware_uart: USB_SERIAL_JTAG
  level: DEBUG

api:
  encryption:
    key: !secret api_encryption_key

ota:
  - platform: esphome
    password: !secret ota_password

wifi:
  ssid: !secret wifi_ssid
  password: !secret wifi_password
  # Se il WiFi non è raggiungibile crea una rete "Citofono-Setup" per configurarlo dal telefono
  ap:
    ssid: "Citofono-Setup"
    password: !secret fallback_ap_password

captive_portal:

# Pagina web locale (http://citofono-vintage.local): funziona anche senza Home Assistant
web_server:
  version: 3
  port: 80
  auth:
    username: admin
    password: !secret web_password

time:
  - platform: sntp
    id: sntp_time
    timezone: Europe/Rome

# -----------------------------------------------------------------------------
#  Stato interno
# -----------------------------------------------------------------------------
globals:
  - id: pulse_count
    type: int
    initial_value: "0"
  - id: dialed_code
    type: std::string
    initial_value: '""'
  - id: remote_hook_used
    type: bool
    initial_value: "false"
  - id: calls
    type: int
    restore_value: true
    initial_value: "0"

# -----------------------------------------------------------------------------
#  Uscite (relè e buzzer) — interne: si comandano solo tramite gli script qui sotto
# -----------------------------------------------------------------------------
switch:
  - platform: gpio
    id: relay_open
    name: "Relè apriporta (K1)"
    pin: GPIO7
    restore_mode: ALWAYS_OFF
    internal: true
    on_turn_on:
      # Interblocco: il relè apriporta non resta mai chiuso più di 5 s
      - delay: 5s
      - switch.turn_off: relay_open

  - platform: gpio
    id: relay_hook
    name: "Sgancio simulato (K2)"
    pin: GPIO17
    restore_mode: ALWAYS_OFF
    on_turn_on:
      # Interblocco: la linea non resta impegnata più di 2 minuti
      - delay: 120s
      - switch.turn_off: relay_hook

  - platform: gpio
    id: buzzer
    pin: GPIO15
    restore_mode: ALWAYS_OFF
    internal: true

  # Opzioni configurabili (ricordate dopo un riavvio)
  - platform: template
    id: dnd
    name: "Non disturbare"
    icon: mdi:bell-off
    optimistic: true
    restore_mode: RESTORE_DEFAULT_OFF
    entity_category: config

  - platform: template
    id: auto_open
    name: "Apertura automatica alla chiamata"
    icon: mdi:door-open
    optimistic: true
    restore_mode: ALWAYS_OFF

  - platform: template
    id: remote_uses_hook
    name: "Apertura remota con sgancio simulato"
    icon: mdi:phone-hangup
    optimistic: true
    restore_mode: RESTORE_DEFAULT_ON
    entity_category: config

  - platform: template
    id: require_handset
    name: "Rotella apre solo a cornetta alzata"
    icon: mdi:phone-classic
    optimistic: true
    restore_mode: RESTORE_DEFAULT_OFF
    entity_category: config

output:
  - platform: gpio
    id: led_out
    pin: GPIO8

light:
  - platform: binary
    id: status_light
    name: "LED di stato"
    output: led_out
    internal: true
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

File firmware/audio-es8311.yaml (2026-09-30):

# =============================================================================
#  Pacchetto ESPHome per la SCHEDA AUDIO ES8311 (daughterboard su J8/J9/J10)
#
#  Si aggiunge al firmware principale, in citofono-vintage.yaml:
#
#    packages:
#      audio: !include audio-es8311.yaml
#
#  Mappa (J8 della scheda madre):
#    IO16 MCLK   IO9 BCLK   IO10 LRCLK   IO11 DOUT (ESP -> codec)   IO12 DIN (codec -> ESP)
#    IO13 SDA    IO14 SCL   -> ES8311 @0x18, TCA9554 @0x20
#  TCA9554: P0 = relè audio K1 (linea al codec), P1 = LED "audio remoto" (acceso basso)
#
#  Questo pacchetto rende disponibili microfono (= voce dal posto esterno) e
#  altoparlante (= voce verso il posto esterno). Il componente che li collega
#  al telefono (SIP/WebRTC, es. esphome-intercom) si aggiunge sopra a questi id:
#    microphone: citofono_mic     speaker: citofono_spk     audio_dac: codec
# =============================================================================

i2c:
  id: bus_audio
  sda: GPIO13
  scl: GPIO14
  frequency: 400kHz

i2s_audio:
  - id: i2s_bus
    i2s_lrclk_pin: GPIO10
    i2s_bclk_pin: GPIO9
    i2s_mclk_pin: GPIO16

audio_dac:
  - platform: es8311
    id: codec
    i2c_id: bus_audio
    address: 0x18
    use_mclk: true
    use_microphone: true
    # Il segnale arriva attenuato di ~17 dB dalla presa ad alta impedenza:
    # si parte da 24 dB e si regola al collaudo (0DB ... 42DB)
    mic_gain: 24DB
    sample_rate: 16000
    bits_per_sample: 16bit

microphone:
  - platform: i2s_audio
    id: citofono_mic
    i2s_audio_id: i2s_bus
    i2s_din_pin: GPIO12
    adc_type: external
    pdm: false
    sample_rate: 16000
    bits_per_sample: 16bit
    channel: left

speaker:
  - platform: i2s_audio
    id: citofono_spk
    i2s_audio_id: i2s_bus
    i2s_dout_pin: GPIO11
    dac_type: external
    audio_dac: codec
    sample_rate: 16000
    bits_per_sample: 16bit
    channel: mono

pca9554:
  - id: espansore_audio
    i2c_id: bus_audio
    address: 0x20

switch:
  # Relè K1 della scheda audio: ON = linea collegata al codec (cornetta esclusa)
  - platform: gpio
    id: relay_audio
    name: "Relè audio (scheda ES8311)"
    internal: true
    restore_mode: ALWAYS_OFF
    pin:
      pca9554: espansore_audio
      number: 0
      mode:
        output: true

  - platform: gpio
    id: led_audio
    internal: true
    restore_mode: ALWAYS_OFF
    pin:
      pca9554: espansore_audio
      number: 1
      inverted: true
      mode:
        output: true

  # Comando unico per Home Assistant: "rispondo da remoto"
  - platform: template
    id: remote_audio
    name: "Rispondi da remoto (audio)"
    icon: mdi:phone-in-talk
    optimistic: true
    restore_mode: ALWAYS_OFF
    turn_on_action:
      - switch.turn_on: relay_hook      # K2 scheda madre: impegna la linea URMET
      - delay: 200ms
      - switch.turn_on: relay_audio     # K1 scheda audio: linea -> codec
      - switch.turn_on: led_audio
      - script.execute: remote_audio_timeout
    turn_off_action:
      - script.stop: remote_audio_timeout
      - switch.turn_off: relay_audio
      - switch.turn_off: led_audio
      - switch.turn_off: relay_hook

script:
  # Sicurezza: la conversazione remota si chiude da sola dopo 2 minuti
  - id: remote_audio_timeout
    mode: restart
    then:
      - delay: 120s
      - switch.turn_off: remote_audio

number:
  - platform: template
    id: volume_uscita
    name: "Volume voce verso la strada"
    icon: mdi:volume-high
    min_value: 0
    max_value: 100
    step: 5
    initial_value: 60
    restore_value: true
    optimistic: true
    on_value:
      - lambda: id(codec).set_volume(x / 100.0f);
